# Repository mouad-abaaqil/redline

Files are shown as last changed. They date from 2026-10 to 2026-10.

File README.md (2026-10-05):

<p align="center">
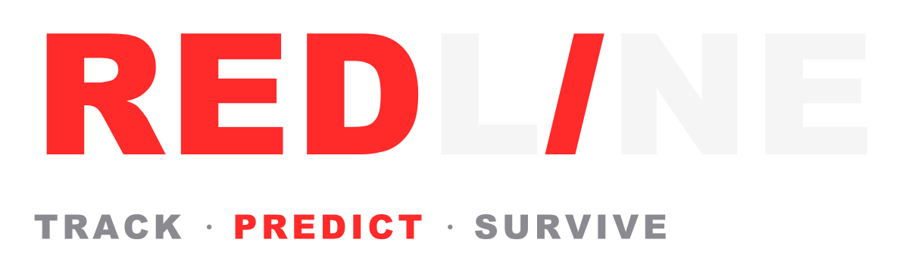
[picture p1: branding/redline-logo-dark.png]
Redline: Track, Predict, Survive
  
</p>

<h1 align="center">Know where it is.<br>Know when it lands.<br><span>Know what happened.</span></h1>

<p align="center">
  <strong>Redline</strong> is a free, open source tracker and black box for freight.<br>
  It knows its exact position, predicts its arrival from real open traffic data, spots a detour or a theft, and keeps talking when every normal network is gone.
</p>

<p align="center">
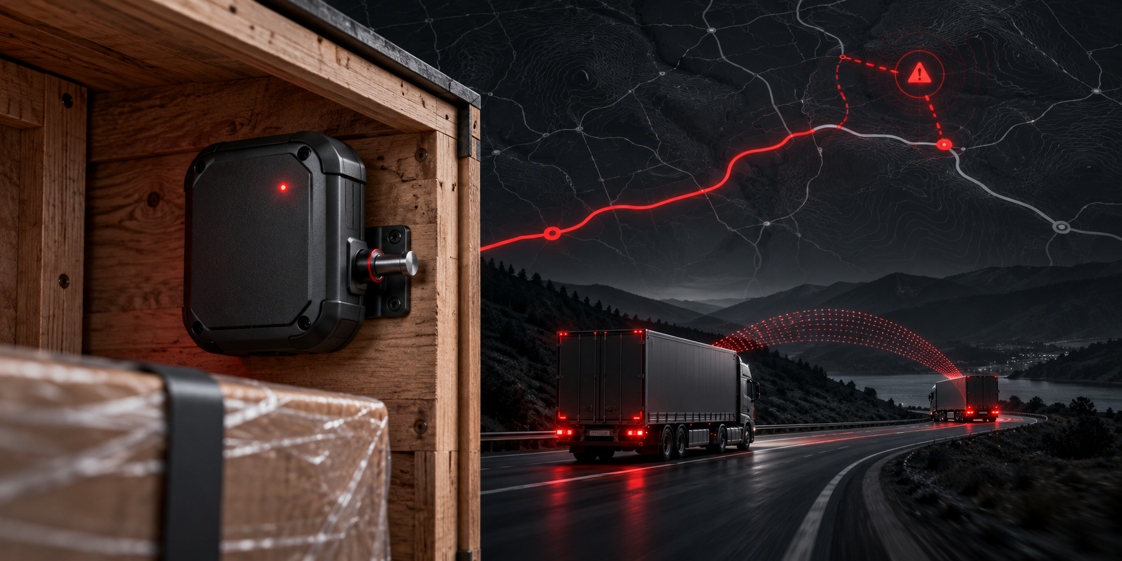
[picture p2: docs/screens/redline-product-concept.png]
Concept illustration of the Redline freight tracker monitoring cargo, route deviation, and a fleet relay
  
</p>
<p align="center"><sub>Product concept: a tracker watching cargo on the road, with route deviation and fleet relay shown around it. This is an illustration, not a photograph of a manufactured device.</sub></p>

<p align="center">
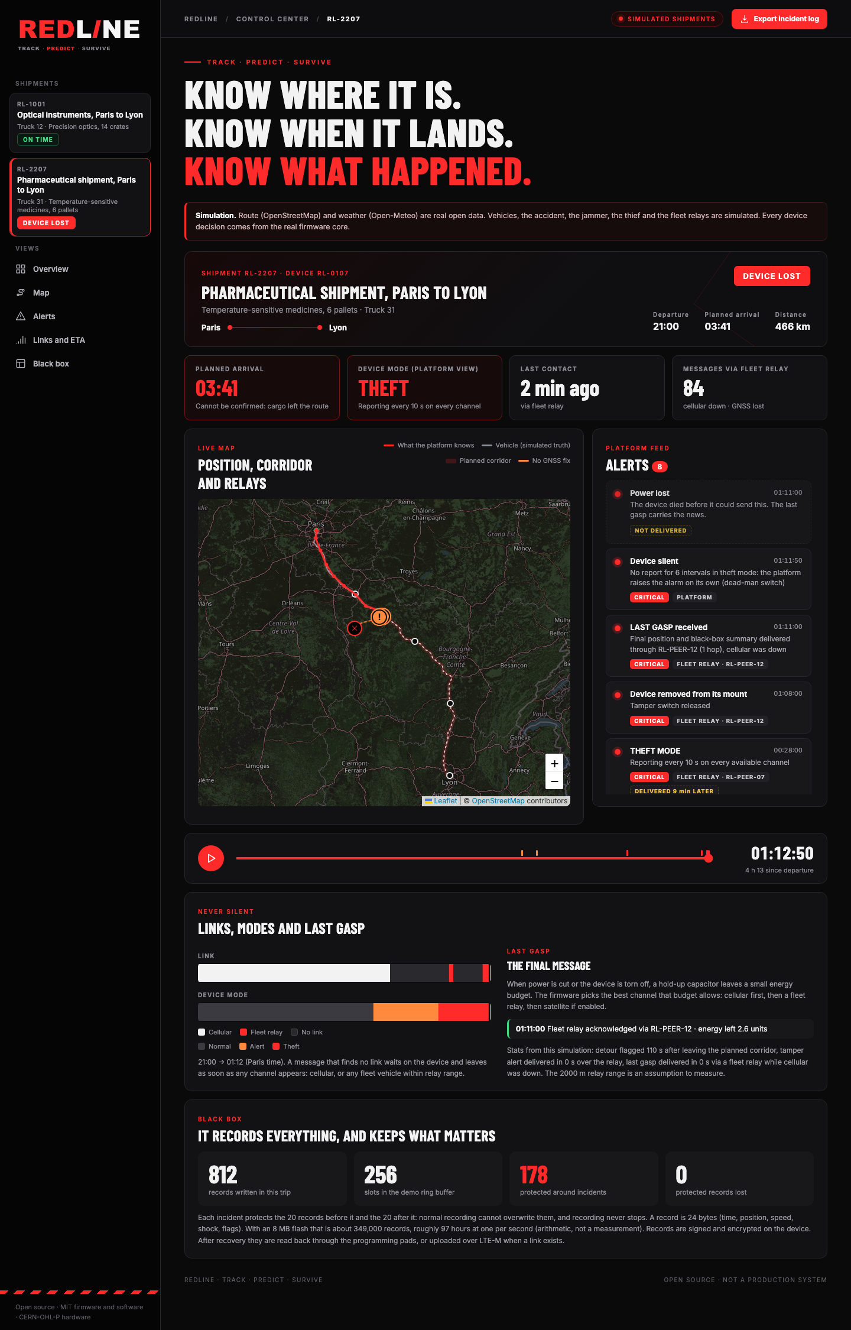
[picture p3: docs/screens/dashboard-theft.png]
Redline control center showing a suspected theft: the platform feed, the map with the planned corridor and the last gasp
  
</p>
<p align="center"><sub>The control center replaying a simulated theft. The road and weather use open data; vehicles, theft events, and fleet relays are simulated. Device decisions come from the firmware core.</sub></p>

> **Successor of [TiltAlert](https://github.com/mouad-abaaqil/TiltAlert).** TiltAlert counts the shocks a parcel takes. Redline tells you where the whole shipment is, when it will arrive, whether it is still on its route, and what happened to it, even if nobody ever finds the device.

---

## 1. The problem: freight goes dark

A truck leaves Paris with six pallets of medicines. Somewhere near Auxerre it takes a road that is not on the plan. Twenty minutes later the cellular network drops. An hour after that the cargo is gone.

What the operator has at that point:

- **A promise, not a prediction.** The ETA was computed at departure. It knows nothing about the accident ahead or the fog that is already there.
- **A tracker that stops talking exactly when it matters.** Thieves jam GNSS and cellular, or just drive into a valley with no coverage.
- **No black box.** When the device is torn off and thrown away, everything it knew goes with it.
- **Tools you rent, with data you do not own.** The price is per device per month and the logic is a secret.

## 2. The solution: three promises, one device

### TRACK: exact position, and the discipline to notice when something is wrong

- **Position** from GNSS, reported every 15 minutes in normal mode, every 60 s in alert mode, every 10 s in theft mode.
- **Route corridor.** The planned route is loaded in the device with a corridor around it. Leaving it for 2 minutes raises an alert. This runs **on the device**, so it works with no network and the alert leaves as soon as any link appears.
- **Unauthorized stop.** Ten minutes still outside every authorized zone (depots, planned rest stops) is flagged. If GNSS is jammed, the accelerometer still says whether the vehicle moves.
- **Theft rules.** Movement while parked and armed, the device pulled off its mount (a spring plunger and a switch), the cover opened, the power cut, and GNSS lost *while the cellular link is healthy*, which points to a jammer. Each condition has a weight: a detour alone raises an alert, a tamper alone is theft.
- **Shock.** The shock sensor of TiltAlert (±200 g) stays, now feeding the black box.

### PREDICT: an arrival time that listens to the road

The engine ([`web/src/eta.js`](./web/src/eta.js), 8 unit tests) is pure and replayable. It combines:

| Input | Source | Cost |
| --- | --- | --- |
| Road network and free-flow speeds | [OpenStreetMap](https://www.openstreetmap.org/copyright), routed by [OSRM](https://project-osrm.org/) (Valhalla also supports per-hour speed profiles) | free |
| Traffic situations (accidents, roadworks) | National access points publishing [DATEX II](https://www.datex2.eu/), for example [transport.data.gouv.fr](https://transport.data.gouv.fr/) | free |
| Weather: rain, visibility, wind | [Open-Meteo](https://open-meteo.com/en/about) (CC BY 4.0, free for open source, self-hostable) | free |
| What the fleet actually measures | Speeds from the trackers themselves | free |
| Mandatory driver breaks | 45 min after 4.5 h of driving (rule to check per vehicle class) | free |

A traffic situation only counts **once it has been published**: the estimate never uses information that did not exist yet.

### SURVIVE: the device that never goes silent

- **Black box.** Every second: position, speed, shock, link state, tamper. In a ring buffer where the 20 records before and after each incident are **protected** from being overwritten. Recording never stops. Records are signed and encrypted.
- **Three communication layers.** Cellular LTE-M/NB-IoT first. When it is down, a **fleet relay**: the message hops through any Redline device in range, over DECT NR+ mesh, like Find My but for freight. Satellite NB-NTN is an option, off by default (it is the only paid layer).
- **Last gasp.** A hold-up supercapacitor leaves a small energy budget when the device is torn off or the supply is cut. The firmware spends it on the best channel available: cellular, then a fleet relay, then satellite.
- **Dead-man switch.** If the device stops reporting while in theft mode, the platform raises the alarm itself.

---

## 3. See it work

Two simulated shipments, Paris to Lyon (465 km, the real road, the real forecast). Open [`web/`](./web/) and replay them.

### Shipment 1: the arrival time that learns

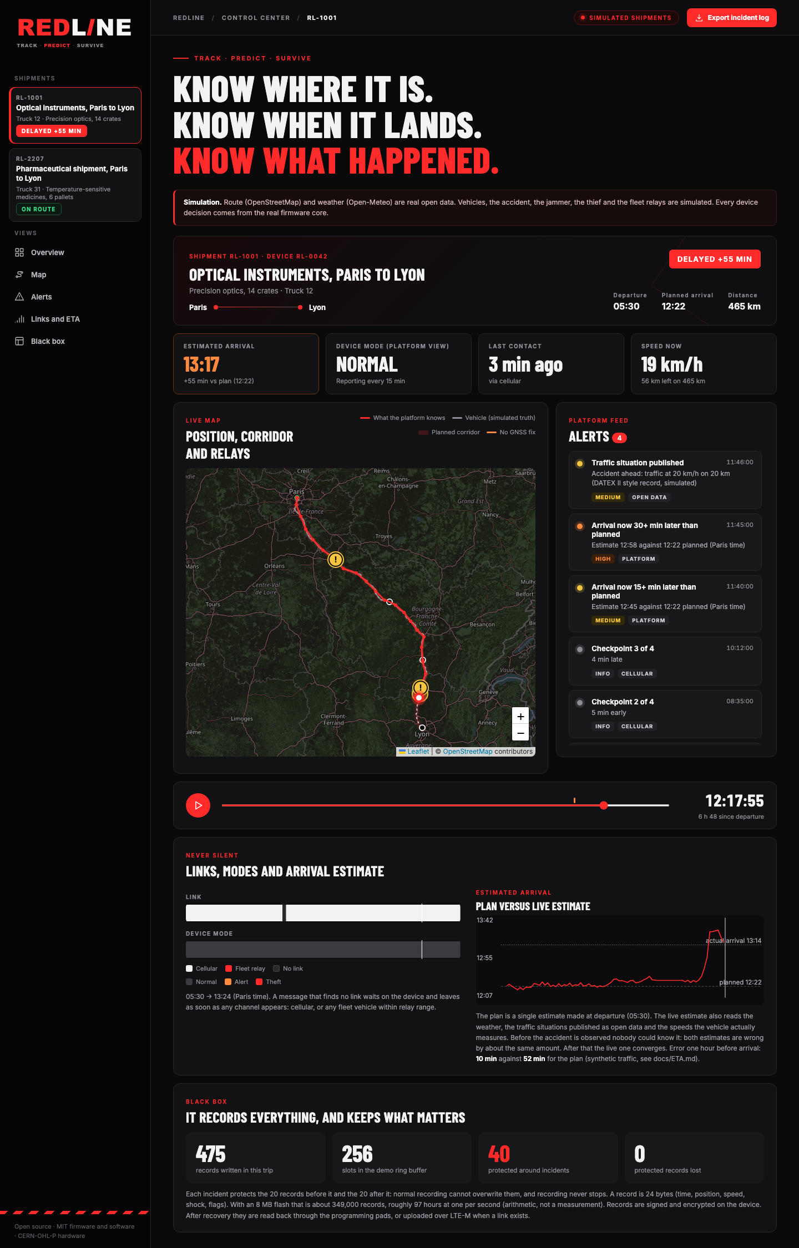
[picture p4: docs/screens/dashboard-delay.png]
The delayed shipment: arrival estimate, accident, link and mode strips


A truck leaves at 05:30 (Paris time) and the plan says it will arrive at 12:22. On the road it meets **real fog** (visibility down to 20 m on the forecast) and a **simulated accident** published at 11:46. It arrives at 13:14, **52 minutes late**.

| | Error on the arrival time |
| --- | --- |
| The plan made at departure | 52 min |
| Live estimate, 60 min before arrival | **10 min** |
| Live estimate, 15 min before arrival | **1 min** |

The live estimate cannot know about an accident before it is published: for the first hours it is as wrong as the plan. Once the situation is published and the truck slows down, it converges. The traffic pattern is synthetic, so these numbers show the mechanism, not a field result ([details](./docs/ETA.md)).

### Shipment 2: theft, jamming, and a last word through a stranger

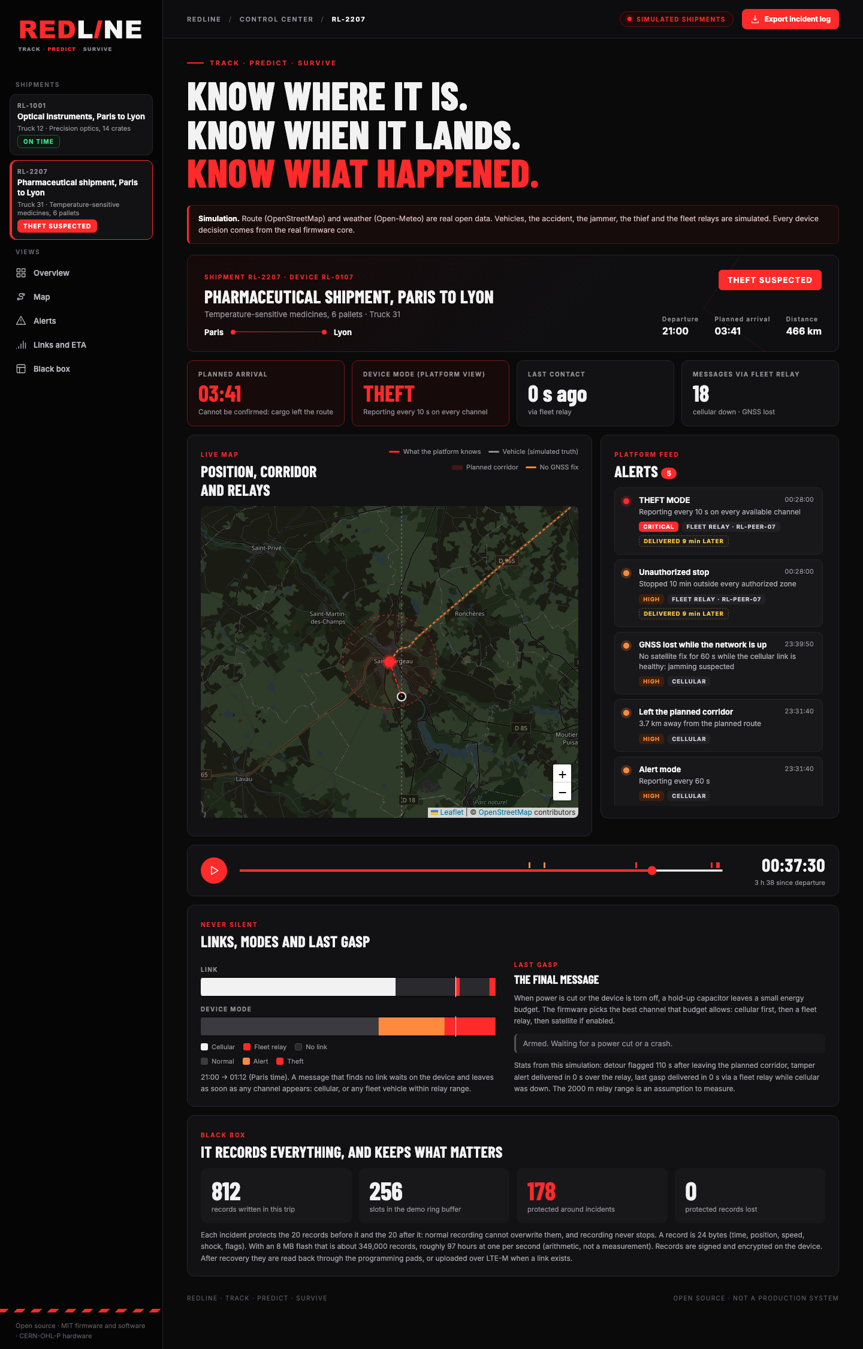
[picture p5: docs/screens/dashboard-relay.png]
The theft shipment 38 minutes later, relay message delivered


1. **21:31** The truck leaves the corridor. Alert delivered over cellular in about 2 minutes.
2. **21:39** GNSS lost while cellular is up: jamming suspected.
3. **22:28** The truck stops 10 minutes at an isolated site. Cellular is gone, so the **theft alert waits on the device for 9 minutes**, then goes through a passing fleet truck (RL-PEER-07).
4. **23:08** The device is torn off its mount. Tamper alert delivered **instantly** through another fleet truck.
5. **23:11** Power cut. The **last gasp** leaves in the same second over the fleet relay. The platform also raises a *device silent* alarm on its own.
6. Black box: 812 records, **178 protected** around the incidents, **0 lost**.

The 2 km relay range and the energy costs are **assumptions to measure on hardware**.

### The hardware, all components on one page

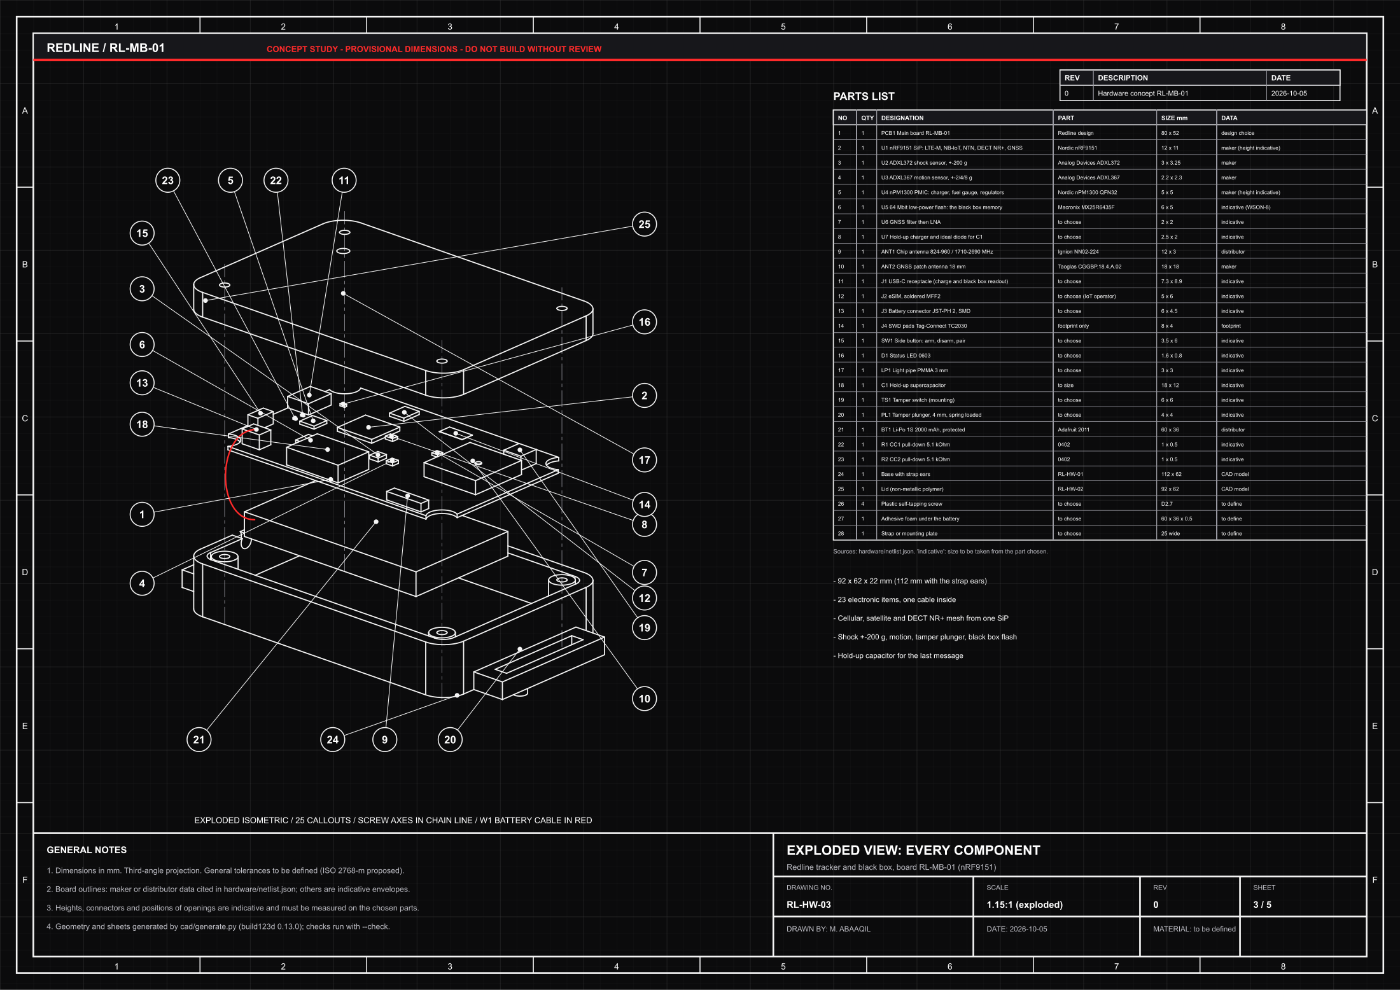
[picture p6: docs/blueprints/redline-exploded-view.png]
Exploded view of the Redline tracker: 25 callouts, parts list, battery cable


Five A3 sheets in a blackprint style, all generated from the 3D model and the netlist ([PDF, 5 pages](./docs/blueprints/redline-plans-A3.pdf)): general assembly with section, the board with the **tamper mechanism** in detail, the exploded view above, the electrical architecture, and the full wiring (33 nets, connector pin-outs, the one cable, power-up sequence).

<details>
<summary><strong>The other four sheets and the interface blueprint</strong></summary>

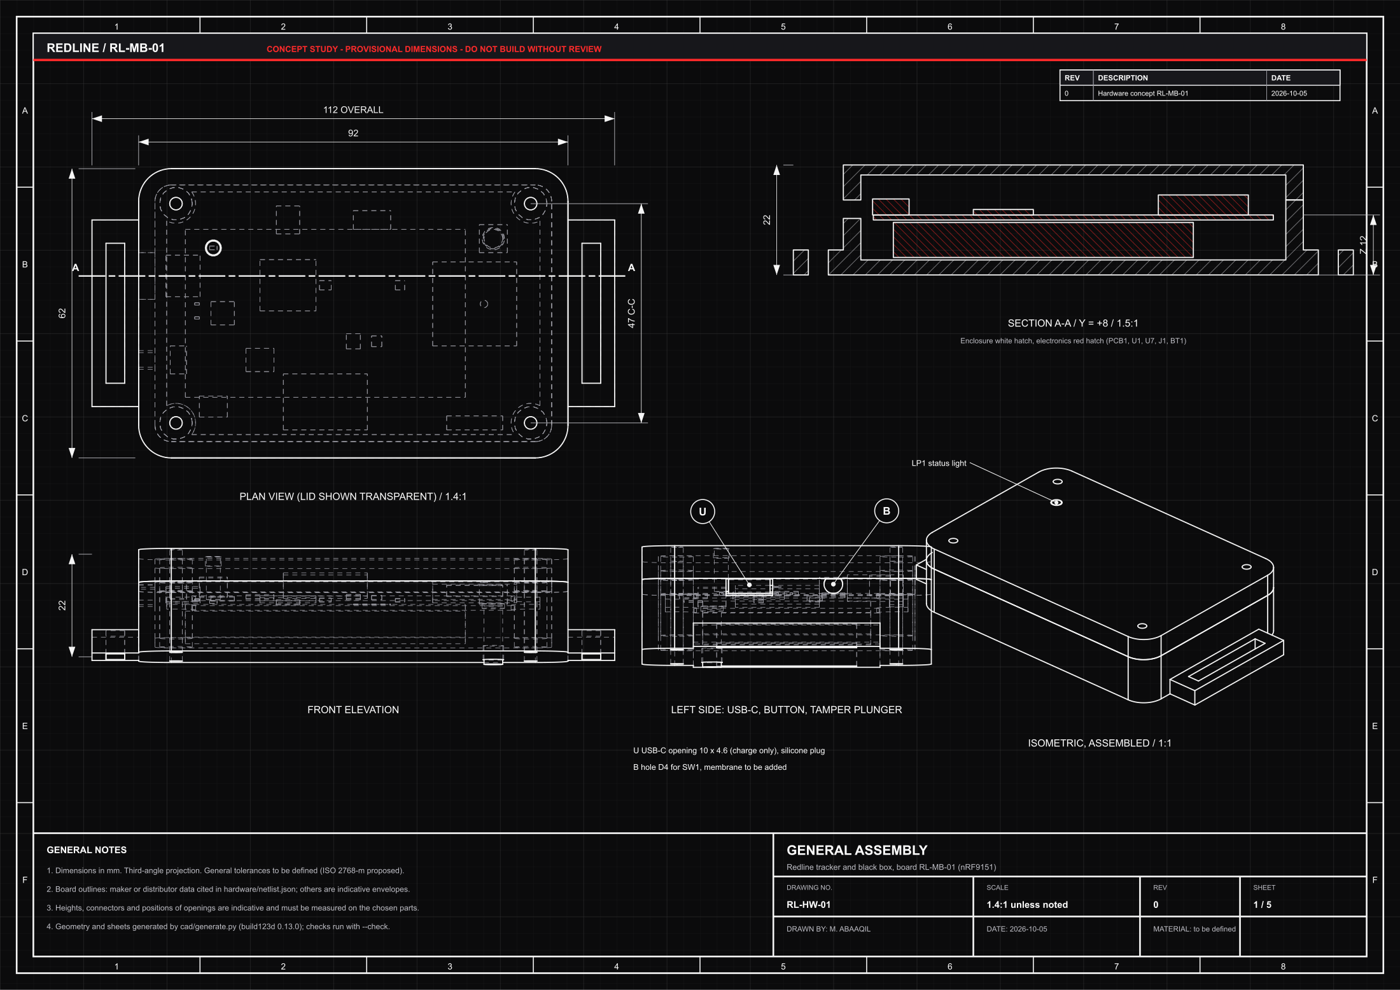
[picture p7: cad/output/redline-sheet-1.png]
Sheet 1: general assembly


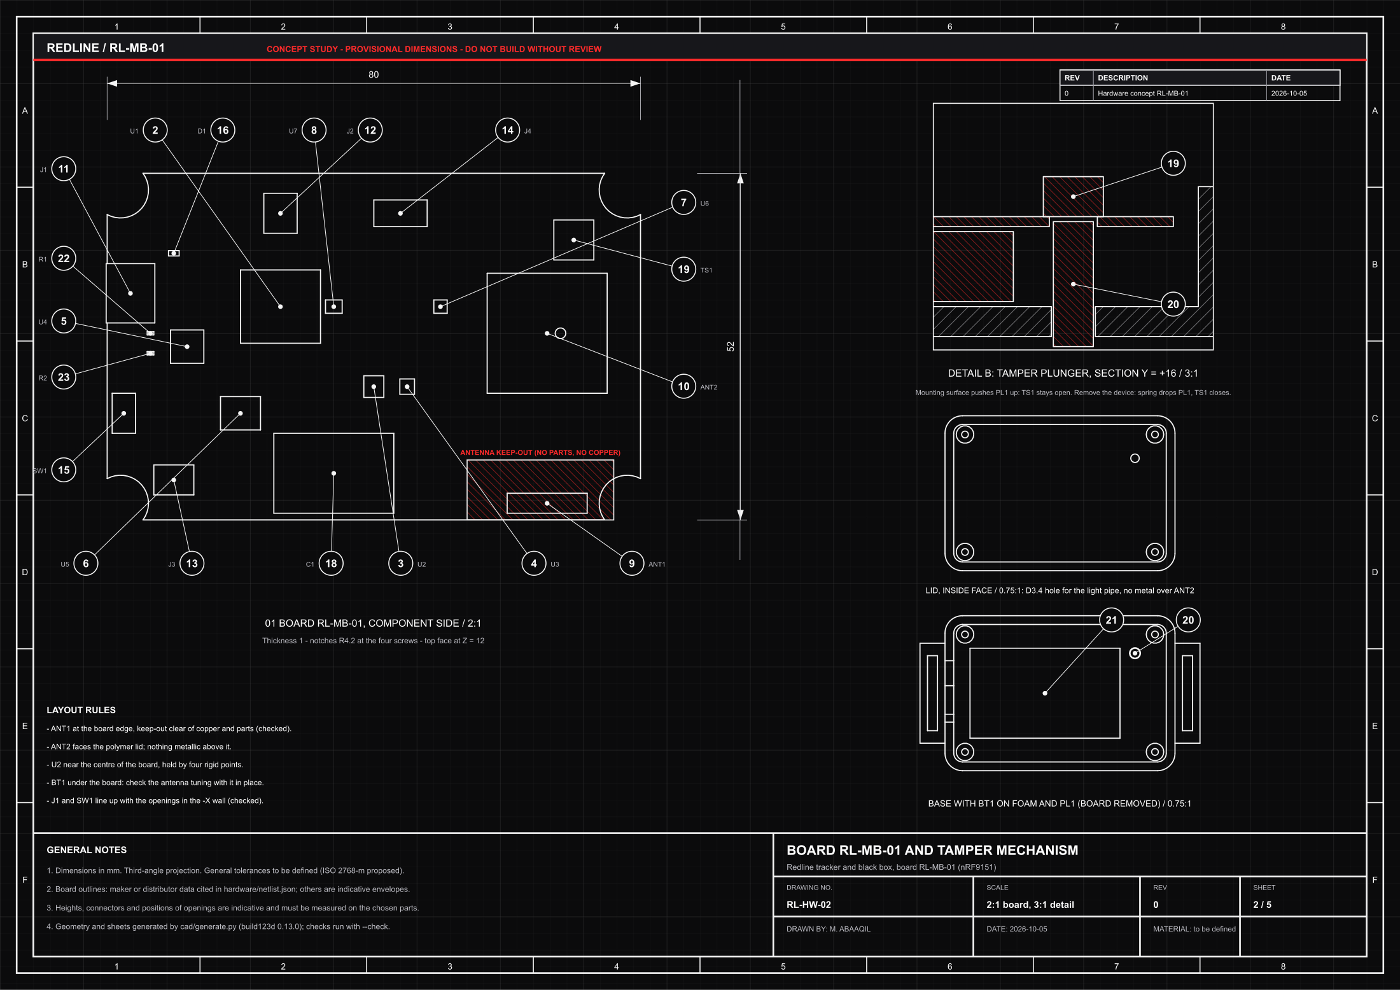
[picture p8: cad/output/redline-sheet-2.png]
Sheet 2: board RL-MB-01 and tamper mechanism


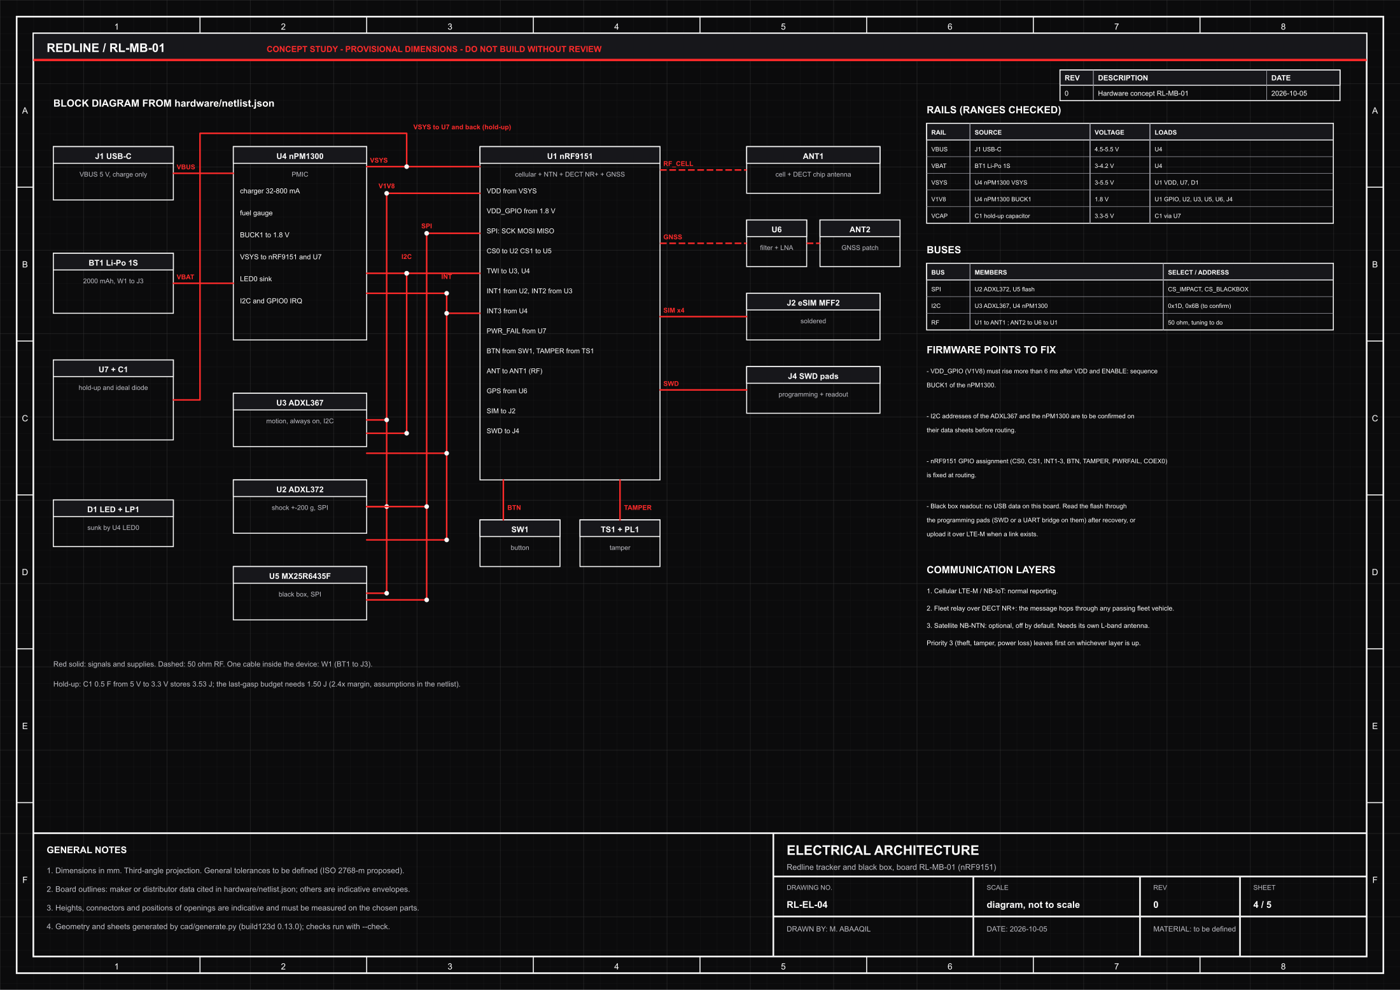
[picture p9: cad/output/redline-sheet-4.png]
Sheet 4: electrical architecture


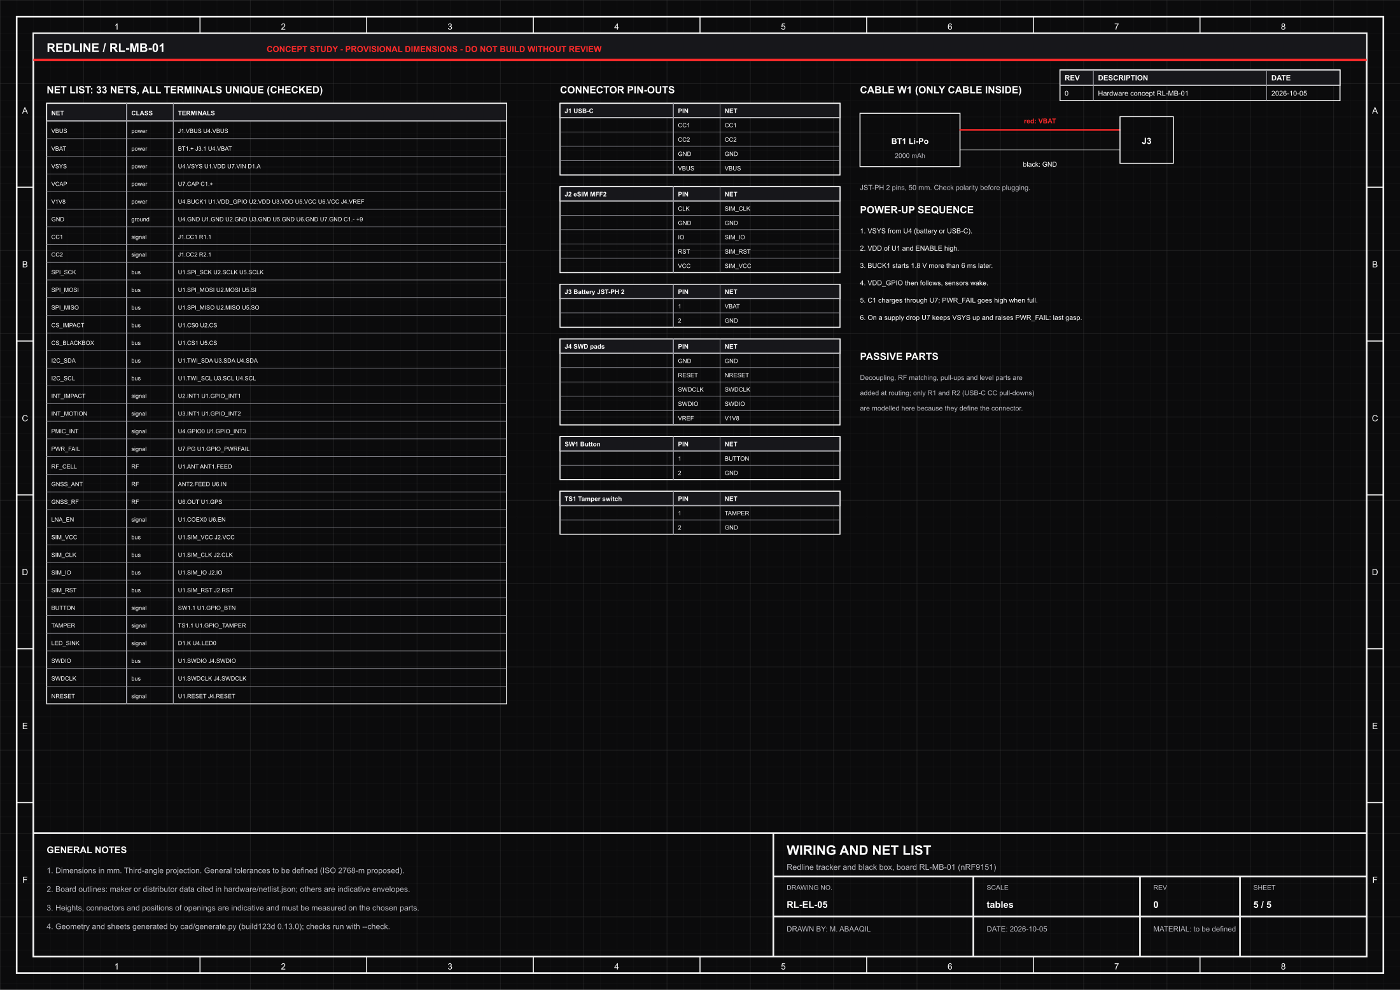
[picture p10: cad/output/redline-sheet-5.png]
Sheet 5: wiring and net list


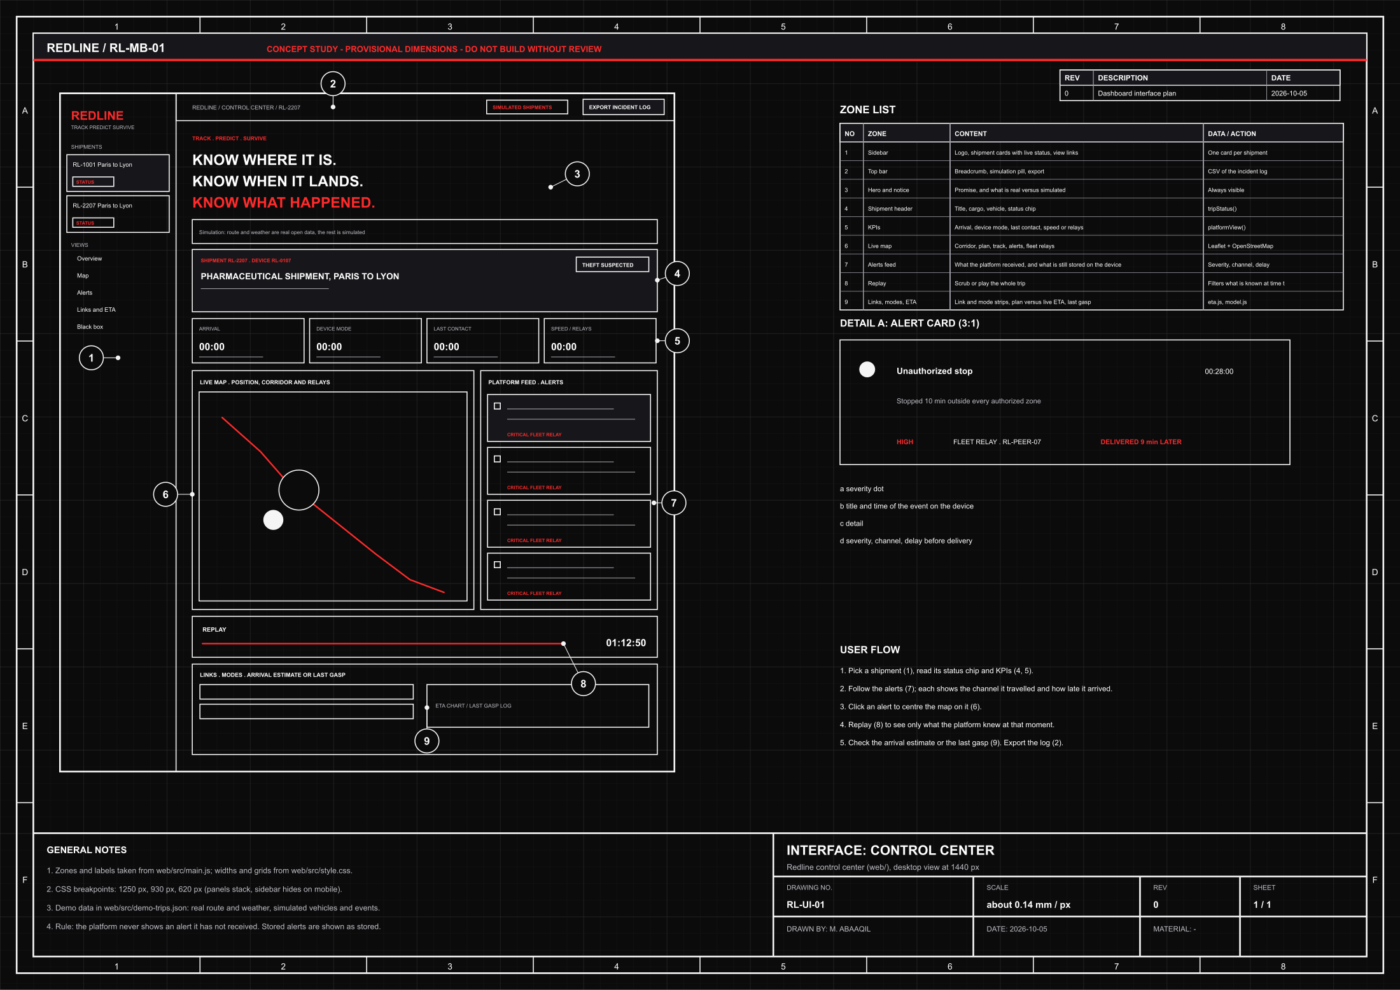
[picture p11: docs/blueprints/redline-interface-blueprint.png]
Interface blueprint of the control center


</details>

---

## 4. Under the hood

One custom board, **RL-MB-01**, in a 92 × 62 × 22 mm enclosure. Every part is in [`hardware/netlist.json`](./hardware/netlist.json) with its source.

| Function | Part | Why |
| --- | --- | --- |
| Brain, cellular, mesh, satellite, GNSS | [Nordic nRF9151](https://www.nordicsemi.com/products/nrf9151) | One SiP supports LTE-M, NB-IoT, [NB-NTN satellite](https://www.nordicsemi.com/products/nrf9151), DECT NR+ mesh and GNSS. |
| Shock, black box trigger | [ADXL372](https://www.analog.com/en/products/adxl372.html), ±200 g | Peak capture and FIFO for the pre-trigger waveform. |
| Motion, always on | [ADXL367](https://www.analog.com/en/products/adxl367.html) | Wakes the system, tells moving from still when GNSS is jammed. |
| Power | [nPM1300](https://www.nordicsemi.com/Products/nPM1300) | Charger, fuel gauge, regulators in one chip. |
| Black box memory | 64 Mbit low-power flash | About 349,000 records of 24 bytes, roughly 97 hours at 1 Hz (arithmetic, not a measurement). |
| Last gasp | Supercapacitor 0.5 F + hold-up charger | 3.5 J stored against 1.5 J needed (2.4×, assumptions in the netlist). |
| Tamper | Spring plunger + switch | The mounting surface holds the switch open; removal closes it. |
| Antennas | Chip antenna (cellular, DECT) + GNSS patch | Keep-out zone enforced in the model. The satellite layer needs its own L-band antenna. |

### A design that checks itself

Every time the drawings are generated, a script verifies that:

- all **23 parts fit** the enclosure without touching a wall, a screw boss or each other (≥ 0.2 mm);
- every **supply rail is inside the range** of every part it powers, and no rail is shorted to another;
- **SPI chip selects and I²C addresses** are distinct;
- the **antenna keep-out** is empty, and no part hangs over a screw notch of the board;
- the **USB-C and button openings** really cross the wall in front of their parts;
- the **hold-up capacitor stores at least twice** the energy the last-gasp budget needs.

### The firmware core is tested, not just written

[`firmware/RedlineCore.h`](./firmware/RedlineCore.h) is plain C++11 with no heap and no dependency, so the same code runs in the tests, in the simulation and on the device. `sh tests/run.sh` runs 9 test groups: geometry, route deviation with hysteresis, stops, schedule, jamming, theft rules, the black box ring buffer, the last-gasp channel choice, and the relay queue with priorities and duplicate protection.

```mermaid
flowchart LR
  A[ADXL372 shock] --> M[nRF9151 + Redline core]
  B[ADXL367 motion] --> M
  T[Tamper plunger] --> M
  G[GNSS] --> M
  M --> K[(Black box flash)]
  M -->|1 normal| C[Cellular LTE-M / NB-IoT]
  M -->|2 no network| R[Fleet relay: DECT NR+ mesh]
  M -->|3 optional| S[Satellite NB-NTN]
  C & R & S --> P[Platform: ETA, alerts, dead-man switch]
  O[(Open data: OSM, DATEX II, Open-Meteo)] --> P
  H[Hold-up capacitor] -.last gasp.-> M
```

---

## 5. Honest status

| ✅ Proven in this repository | 🔬 To prove on real hardware |
| --- | --- |
| Core logic: deviation, stops, schedule, jamming, theft score, black box, last gasp, relay queue (tested C++). | Detection thresholds and false positives on real trucks. |
| ETA engine: breaks, rush hour, weather, published incidents, fleet correction (tested JS). | Accuracy on real traffic, against a measured weekly speed profile. |
| Two end-to-end simulated trips with real route and weather data, replayed in the dashboard. | Mesh range, relay behaviour in a moving fleet, DECT NR+ with real firmware. |
| Hardware checked by script: fit, rails, buses, keep-out, hold-up energy. | Antenna tuning with the battery in place, satellite layer, hold-up ESR during the LTE-M burst. |
| Plans, STEP and STL generated from the model. | Autonomy, enclosure test, transport of lithium cells (regulated). |

**Not claimed:** any accuracy, autonomy or cost figure. GNSS jamming detection is an aid, not a guarantee. A signature proves a log was not altered, not that a court accepts it. Satellite service in Europe depends on operators such as [Skylo](https://www.skylo.tech/newsroom/deutsche-telekom-murata-and-skylo-technologies-announce-satellites-nb-iot-ntn-early-adopter-program-for-europe) and costs money.

**Privacy.** Redline tracks **cargo, not people**. Using location data on a driver falls under labour law and the GDPR in Europe. See [`docs/PRIVACY_AND_ETHICS.md`](./docs/PRIVACY_AND_ETHICS.md): design rules, and what the system deliberately does not do.

### Next

1. Write the firmware on a [Nordic Thingy:91 X](https://docs.nordicsemi.com/r/bundle/ug_thingy91x/page/ug/thingy91x/intro/frontpage.html) (same SiP and PMIC): core logic, black box, LTE-M reporting.
2. Measure a weekly speed profile on a real corridor and replace the synthetic traffic pattern.
3. Test fleet relay range with two or three devices.
4. Route the PCB (4 layers), RF review, hold-up measurements.
5. Prototype the enclosure and test the tamper mechanism.

---

## 6. Explore the repository

| | |
| --- | --- |
| [`web/`](./web/) | Control center: live map, alerts with channel and delay, replay, ETA chart, last gasp, black box, CSV export. |
| [`firmware/RedlineCore.h`](./firmware/RedlineCore.h) | The device logic, tested. |
| [`simulation/`](./simulation/README.md) | Trip runner (links the real core), real route and weather snapshots, scenario generator. |
| [`hardware/`](./hardware/README.md) | Netlist, component choices, checks, points to settle before routing. |
| [`cad/`](./cad/README.md) | Parametric enclosure and the five A3 sheets (build123d). |
| [`docs/`](./docs/) | [Architecture](./docs/ARCHITECTURE.md) · [ETA](./docs/ETA.md) · [Mesh and last gasp](./docs/MESH_AND_LAST_GASP.md) · [Privacy and ethics](./docs/PRIVACY_AND_ETHICS.md) |
| [`branding/`](./branding/) | The logo files (SVG, generated). |

## 7. Run it

```bash
sh scripts/check.sh                 # all tests and checks (see below)

# Control center
cd web && npm ci && npm run dev     # then open the address Vite prints

# Regenerate the hardware drawings (Python 3.12, rsvg-convert)
python3.12 -m venv .venv && .venv/bin/pip install -r cad/requirements.txt
.venv/bin/python cad/generate.py            # sheets, STEP, STL
python3 docs/interface/generate.py          # interface blueprint

# Regenerate the simulated trips (only needs g++ and Node 20+)
node simulation/fetch-data.mjs              # optional: refresh the open-data snapshots
node simulation/make-scenario.mjs           # rebuilds web/src/demo-trips.json
```

`scripts/check.sh` runs the C++ tests, the web tests (ETA engine and dashboard model), the geometry and netlist checks, and rebuilds the dashboard.

## 8. Open source, for real

| | License |
| --- | --- |
| Firmware, software, simulation, drawings code | [MIT](./LICENSE) |
| Hardware design (netlist, enclosure model, plans) | [CERN-OHL-P v2](./LICENSE-HARDWARE.txt) (permissive) |
| Data | OpenStreetMap contributors (ODbL), Open-Meteo (CC BY 4.0). See [NOTICE](./NOTICE.md). |

---

<p align="center">
  <strong>REDLINE</strong> · Track · Predict · Survive<br>
  <sub>A concept with checked foundations, not a product. Dimensions and architecture are not validated for manufacture.</sub>
</p>

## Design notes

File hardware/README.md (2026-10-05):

# Hardware: board RL-MB-01

**Status: design with sourced parts. The PCB is not routed, nothing is built or measured.**

[`netlist.json`](./netlist.json) is the single source: 23 components with a size, a source or an "indicative" mark, 33 nets, rails with their ranges, buses, the one cable, and the hold-up assumptions. The drawings in [`../cad/`](../cad/README.md) are generated from it.

## What changed from TiltAlert

TiltAlert V1 is an Arduino Uno with a tilt contact. Its V2 study used a tracker with GNSS and LTE-M. Redline keeps that core (nRF9151, ADXL372, ADXL367, nPM1300, black box flash) and adds what the new product needs: a **hold-up capacitor** (U7, C1) for the last gasp, a **tamper mechanism** (TS1 with a spring plunger PL1 through the floor), the **DECT NR+ and NTN** layers (same SiP, no new chip), and an enclosure sized for it.

## Parts and sources

| Ref | Part | Source |
| --- | --- | --- |
| U1 | Nordic nRF9151 | https://www.nordicsemi.com/products/nrf9151 |
| U2 | Analog Devices ADXL372 | https://www.analog.com/en/products/adxl372.html |
| U3 | Analog Devices ADXL367 | https://www.analog.com/en/products/adxl367.html |
| U4 | Nordic nPM1300 | https://www.nordicsemi.com/Products/nPM1300 |
| U5 | Macronix MX25R6435F | https://www.mouser.fr/new/macronix/macronix-mx25r-nor-flash |
| ANT1 | Ignion NN02-224 | https://www.digikey.ph/en/products/detail/ignion/NN02-224/10108260 |
| ANT2 | Taoglas CGGBP.18.4.A.02 | https://www.taoglas.com/product/cggbp-18-4-a-02-gpsglonassbeidou-patch-antenna-18mm-2 |
| BT1 | Adafruit 2011 (3.7 V, 2000 mAh) | https://www.adafruit.com/product/2011 |

Parts marked "to choose" (USB-C, eSIM, connectors, button, LED, light pipe, hold-up charger, capacitor, tamper switch and plunger) have indicative envelopes only.

## Points to settle before routing

1. **Satellite antenna.** The chip antenna covers 824-960 and 1710-2690 MHz. NB-NTN uses L-band near 1.6 GHz, which is not covered. If the satellite layer is enabled it needs its own antenna and a coexistence plan with the GNSS patch.
2. **Hold-up.** The 0.5 F value and the energy unit are assumptions. Measure the capacitor ESR against the LTE-M burst current, and the real energy of a last-gasp message on each channel.
3. **Sequencing.** VDD_GPIO (1.8 V) must rise more than 6 ms after VDD and ENABLE: program BUCK1 of the nPM1300 accordingly.
4. **I²C addresses** of the ADXL367 (0x1D planned) and nPM1300 (0x6B planned) to confirm on the data sheets.
5. **GPIO assignment** of the nRF9151 (CS0, CS1, INT1-3, BTN, TAMPER, PWRFAIL, COEX0) to fix at routing.
6. **Black box readout.** The nRF9151 has no native USB, so the board has no USB data. Read the flash through the programming pads after recovery, or upload it over LTE-M. A USB bridge could be added.
7. **Tamper.** The plunger and spring, their travel and the mounting plate need a mechanical design and a test. A thief can defeat a switch with the right tool: treat it as one signal among several.
8. **Antenna tuning** with the battery in place and the lid on; the lid must stay non-metallic.
9. **Lithium cells** in air transport are regulated: check the rules for the chosen cell and quantity.
10. **Supply margin.** VSYS on battery falls to 3.0 V at cutoff, exactly the minimum of the nRF9151 VDD. There is no margin for sag during a transmit burst: measure it, and stop earlier with a software threshold if needed.

## Validation order

1. Firmware on a Nordic Thingy:91 X: core logic, black box, LTE-M reporting.
2. Route the PCB on four layers, then an RF review.
3. Bring up: rails, sequencing, SWD, sensor reads, flash.
4. Calibrated shocks, tilts and false-positive tests with the board fixed in the enclosure.
5. GNSS quality outdoors and in a vehicle, then recording with no network.
6. Hold-up and last-gasp test, fleet relay range test with two or three devices.
7. Autonomy, charge and temperature tests before any claim.

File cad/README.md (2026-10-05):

# Enclosure and drawings

A parametric enclosure for the Redline tracker and the five A3 sheets that describe it, generated from one 3D model.

```sh
python3.12 -m venv .venv
.venv/bin/pip install -r cad/requirements.txt
.venv/bin/python cad/generate.py --check     # checks only
.venv/bin/python cad/generate.py             # sheets, PDF, STEP, STL
```

`rsvg-convert` is needed to produce the PDF and PNG files.

| File | Role |
| --- | --- |
| `generate.py` | Dimensions, enclosure, checks, the five sheets |
| `components.py` | The 23 parts as solids, the floorplan, the netlist validator |
| `drafting.py` | Shared A3 frame: zone border A to F and 1 to 8, revision and title blocks |
| `output/` | `redline-sheet-1..5` (SVG, PDF, PNG), base, lid and assembly STEP, base and lid STL |

## Sheets

1. General assembly: plan, front and side views, exact section through the USB-C port, isometric.
2. Board RL-MB-01 at 2:1 with callouts and the antenna keep-out, the tamper plunger in an exact section at 3:1, lid and base.
3. Exploded view of every part on one page with 25 callouts and a 28-line parts list.
4. Electrical architecture: block diagram, rails, buses, firmware points, communication layers.
5. Wiring: all 33 nets, connector pin-outs, the battery cable, power-up sequence.

The script also writes `docs/blueprints/redline-plans-A3.pdf` (the five sheets) and `redline-exploded-view.svg/png`.

## What `--check` proves

- The enclosure outline, wall openings and the four screw bores are consistent.
- All 23 parts lie inside the cavity and keep at least 0.2 mm from walls, screw bosses and each other. Parts on the board touch it by design only.
- No part enters the LTE antenna keep-out or hangs over a screw notch of the board.
- The netlist is valid: unique terminals and references, every supply pin on its rail with the rail inside the part's range, distinct SPI chip selects and I²C addresses, no short between VSYS, V1V8 and the hold-up rail, and the hold-up capacitor stores at least twice the last-gasp energy.

It does not replace a print test, a mechanical review, or an RF review.

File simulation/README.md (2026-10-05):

# Simulation

Two simulated shipments, Paris to Lyon, built from **real open data** and driven by the **real firmware core**.

```
simulation/data/            snapshots of real data: route-a.json, route-b.json, weather.json
simulation/runner.cpp       compiles with firmware/RedlineCore.h and runs it over a trip
simulation/make-scenario.mjs  builds the vehicles, injects the events, writes web/src/demo-trips.json
simulation/fetch-data.mjs   refreshes the snapshots from OSRM and Open-Meteo
```

## Run

```sh
node simulation/make-scenario.mjs      # needs g++ and Node 20+; rewrites web/src/demo-trips.json
node simulation/fetch-data.mjs         # optional: refetch the open data (network)
```

The generator is deterministic (seeded noise): the same data gives the same trips.

## What is real, what is simulated

| Real | Simulated |
| --- | --- |
| The road: 465 km Paris to Lyon with OpenStreetMap speeds, and a 52 km detour road | The vehicles and their speed noise |
| The weather forecast along the route, hour by hour (fog included) | The traffic accident (published at a chosen time) |
| Every device decision: the code of `RedlineCore.h` runs unchanged in `runner.cpp` | The GNSS jammer, the dead zone, the thief |
| The ETA engine `web/src/eta.js` | Fleet peers and their 2 km relay range (an assumption) |

The traffic congestion pattern in the ETA model is synthetic (see [../docs/ETA.md](../docs/ETA.md)).

## Trips

**RL-1001, the arrival time that learns.** A truck leaves at 05:30 (Paris time), planned arrival 12:22. It meets real fog and a simulated accident. It arrives at 13:14, 52 minutes late. The plan is off by 52 min; the live estimate is off by 10 min one hour before arrival and by 1 min fifteen minutes before. One shock is recorded and sent. The platform raises two ETA-slip alerts. Cellular coverage is lost in one valley and the stored reports go out afterwards.

**RL-2207, theft.** The truck leaves the corridor, GNSS is jammed, the truck stops at an isolated site and cellular is gone. The stop alert waits 9 minutes for a fleet relay. The device is torn off, then its power is cut: the tamper alert and the last gasp go over the fleet relay, and the platform raises the dead-man alarm.

## Runner protocol

`runner.cpp` reads lines: `CFG`, `G` (hold-up budget), `R` (route point), `Z` (authorized zone), `C` (checkpoint), `S` (one sample per tick). It writes JSON lines: `t` ticks, `e` device events, `d` delivered messages with their channel, `g` last-gasp attempts, and a final `end` summary of the black box.

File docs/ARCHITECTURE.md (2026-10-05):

# Architecture

Redline has three parts that only talk through messages: the **device**, the **links**, and the **platform**.

```
 device (RedlineCore + nRF9151)           links                       platform
 ┌──────────────────────────────┐   ┌────────────────────┐   ┌───────────────────────────┐
 │ sensors → Tracker (risk, mode)│   │ 1 cellular          │   │ receives messages         │
 │ BlackBox (ring, protected)    │──▶│ 2 fleet relay (mesh)│──▶│ ETA engine (eta.js)       │
 │ RelayQueue (store and forward)│   │ 3 satellite (opt.)  │   │ alerts, dead-man switch   │
 │ LastGasp (energy budget)      │   └────────────────────┘   │ control center (web/)     │
 └──────────────────────────────┘                             └───────────────────────────┘
```

## What runs where, and why

| Decision | Where | Reason |
| --- | --- | --- |
| Corridor, stop, jamming, theft score, mode | **Device** | Must work with no network. The alert is queued and leaves with the first link. |
| Which channel for which message | **Device** | Only the device knows which links are up and how much energy is left. |
| Arrival estimate | **Platform** | Needs open traffic and weather data and the speeds of the whole fleet. |
| *Device silent* alarm | **Platform** | A dead device cannot report its own death. |

## The device: `firmware/RedlineCore.h`

Plain C++11, no heap, no dependency. Fixed-size buffers: 400 route points, 16 zones, 16 checkpoints, a 256-slot black box in the demo.

- **`Tracker`**: takes one `Sample` per tick (position, speed, GNSS and cellular state, motion, tamper, power, shock, armed) and returns events. A condition must hold for a confirmation time before it fires (2 min for a deviation, 10 min for a stop, 60 s for GNSS loss, 10 s for movement while armed), and a deviation clears only inside 80 % of the corridor, to avoid flapping.
- **Risk and mode.** Each active condition adds a weight; the sum selects the mode. Deviation 40, stop 30, GNSS loss 40, armed motion 60, tamper 100, power loss 100. Alert starts at 40, theft at 100. **Theft is latched** until an operator acknowledges it. The mode sets the reporting interval: 15 min, 60 s, 10 s.
- **`BlackBox<N>`**: ring buffer. `flagIncident(pre, post)` protects the `pre` newest records and the next `post`. When every slot is protected, the oldest is overwritten so recording never stops (the count of overwritten protected records is kept).
- **`LastGasp`**: an energy budget. `next(links)` returns the best affordable channel: cellular, then mesh, then satellite, at most 2 tries per channel. Costs are relative units to calibrate on hardware.
- **`RelayQueue<N>`**: messages carry a priority (0 routine to 3 urgent), a TTL and a hop count. Duplicates are dropped, urgent messages leave first, a full queue evicts the oldest lowest-priority message, and a routine message never displaces an urgent backlog.

## The platform: `web/`

- `eta.js`: the estimate (see [ETA.md](./ETA.md)).
- `model.js`: `platformView(trip, t)` is the key function. It returns only what **was delivered** by time `t`. Everything else is shown as *stored on the device*. `tripStatus` turns that into the headline.
- `main.js`: rendering with Leaflet. The replay slider sets `t`; nothing the platform could not know at `t` is displayed.

## Data flow of one theft alert, in the simulation

1. `Tracker.update()` fires `unauthorized_stop` at 22:28:00 and the risk reaches theft level.
2. The runner creates a priority-3 message in the `RelayQueue`.
3. Cellular is down and no peer is in range: the message stays queued.
4. At 22:37:10 a fleet truck comes within 2 km. The message is popped and delivered through it.
5. `platformView` shows the alert from 22:37:10 with the badge *DELIVERED 9 min LATER*, and the event time stays 22:28:00.

## Simulation boundary

Simulated: vehicles, traffic accident, jammer, thief, fleet peers, radio. **Real:** the road geometry and speeds (OpenStreetMap), the weather (Open-Meteo), and every device decision (the core is compiled and run unchanged by `simulation/runner.cpp`). Radio range and energy costs are assumptions, listed in the README.

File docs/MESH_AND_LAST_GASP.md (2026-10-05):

# Fleet relay and last gasp

## The idea

Apple's Find My works because many devices carry a message that none of them can read. Redline applies the same principle to freight, with an operator-owned fleet instead of a consumer network: **any Redline device that is in range can carry another device's urgent message to the platform.**

## Layers

1. **Cellular (LTE-M / NB-IoT).** Normal reporting. Cheapest in energy per message.
2. **Fleet relay.** The [nRF9151](https://www.nordicsemi.com/products/nrf9151) supports DECT NR+, a mesh radio that needs no operator. A device with no link hands its message to a peer that has one. Messages carry a TTL (6 hops maximum), a priority, and an id so a message already seen is dropped.
3. **Satellite (NB-NTN).** Optional, off by default. The nRF9151 supports it, and services exist in Europe through operators such as [Skylo](https://www.skylo.tech/newsroom/deutsche-telekom-murata-and-skylo-technologies-announce-satellites-nb-iot-ntn-early-adopter-program-for-europe), but it costs money and needs its own L-band antenna (the chip antenna chosen does not cover it).

Priority 3 messages (theft, tamper, power loss) leave first, on whichever layer is up.

## Security model (design intent, not implemented)

- Messages are signed and encrypted end to end between the device and the platform. A relay sees an opaque payload and a priority byte, nothing more.
- A relay never reveals its own position in the message.
- Every device is provisioned with a key at manufacture. A stolen device can be revoked platform-side.

Not designed yet: key management, replay protection across devices, abuse by a malicious node flooding priority 3. These are real problems to solve before this could ship.

## Last gasp

When the supply drops (`PWR_FAIL`) or a crash is detected (shock ≥ 150 g), the firmware spends a fixed energy budget on the best affordable channel.

| Channel | Relative cost | Attempts |
| --- | --- | --- |
| Cellular | 1.0 | 2 |
| Fleet relay | 0.4 | 2 |
| Satellite | 2.5 | 2 |

The budget is 3.0 units. Hold-up check in `hardware/netlist.json`: a 0.5 F capacitor from 5 V to 3.3 V stores 3.53 J; if 1 unit is 0.5 J the budget needs 1.5 J, a 2.4× margin. **Both the unit and the 0.5 F are assumptions.** What decides it in practice is the capacitor's ESR during an LTE-M burst, which must be measured.

## What the simulation shows

In the theft shipment cellular is down for the last hour. The device keeps queuing. Passing fleet trucks (assumed 2 km range) carry 80 of its reports, the delayed theft alert, the tamper alert and the last gasp. The platform separately raises *device silent* when reports stop in theft mode.

## Limits

- A fleet relay only helps where other devices are. A truck alone on a mountain road has no relay.
- DECT NR+ range and behaviour in a moving fleet are unmeasured.
- Relaying consumes energy on devices that are not in trouble. The relay policy (when to accept, how many hops) needs a battery budget.

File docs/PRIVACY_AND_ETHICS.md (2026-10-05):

# Privacy and ethics

Redline tracks **cargo**. Position data attached to a vehicle is also, indirectly, data about the person driving it. In the European Union that falls under the GDPR and under employment law, and the rules differ by country. This file is a design stance, not legal advice.

## Rules the design follows

1. **The unit of tracking is the shipment.** The device is registered to a shipment, not to a driver. The demo data contains no driver identity.
2. **Track only while the cargo is on the move or armed.** Parked and disarmed at a depot, the device reduces its reporting. The route corridor and stops exist to protect the cargo, not to measure a person's behaviour.
3. **The driver is told.** A truck carrying a tracker is a workplace fact; drivers and their representatives must be informed. Rest-stop zones are authorized so that a legal break is never an alert.
4. **No performance scoring.** The break rule in the ETA engine exists to make the estimate honest about regulated rest. Nothing computes a driver's speed ranking, idle time, or stops for evaluation.
5. **Minimise and expire.** The black box and the platform keep what an incident needs. Retention periods must be set by the operator and the black box readout should be a controlled action.
6. **Open and auditable.** The detection logic is public so anyone can check what a device flags and why.

## What Redline deliberately does not do

- It does not identify or follow individuals, and has no map of where a person lives or goes outside the shipment.
- It does not hide itself from the person carrying the cargo by default (the status light can be disabled by the operator, which must be disclosed to the people concerned).
- It does not claim to detect theft with certainty. Jamming detection and the risk score are aids that can be wrong. An alert is a reason to look, not proof.

## Misuse

A tracker that survives removal and reports in secret is also a stalking tool when put on a person's belongings. The same properties that protect freight are dangerous in that use. The project is documented and licensed for freight. Hardware sold as a product would need anti-stalking measures such as alerting the people near an unknown moving tracker, and that is not designed here.

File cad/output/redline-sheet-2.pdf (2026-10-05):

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
A | A
B | B
C | C
D | D
E | E
F | F
REDLINE / RL-MB-01 | CONCEPT STUDY - PROVISIONAL DIMENSIONS - DO NOT BUILD WITHOUT REVIEW
REV | DESCRIPTION | DATE
0 | Hardware concept RL-MB-01 | 2026-10-05

### GENERAL NOTES

1. Dimensions in mm. Third-angle projection. General tolerances to be defined (ISO 2768-m proposed).
2. Board outlines: maker or distributor data cited in hardware/netlist.json; others are indicative envelopes.
3. Heights, connectors and positions of openings are indicative and must be measured on the chosen parts.
4. Geometry and sheets generated by cad/generate.py (build123d 0.13.0); checks run with --check.

## BOARD RL-MB-01 AND TAMPER MECHANISM

Redline tracker and black box, board RL-MB-01 (nRF9151)

DRAWING NO.

### RL-HW-02

SCALE

### 2:1 board, 3:1 detail

REV
0

SHEET
2 / 5
DRAWN BY: M. ABAAQIL | DATE: 2026-10-05 | MATERIAL: to be defined

ANTENNA KEEP-OUT (NO PARTS, NO COPPER)

U1 | 2
U4 | 5
U5 | 6 | 3 U2 | 4 U3

### 7 U6

U7 8

### 10 ANT2

### 9 ANT1

J1 | 11
SW1 | 15
D1 | 16 | J2 | 12
J3 | 13

## 14 J4

C1 18

### 19 TS1

R1 | 22
R2 | 23

80

52

### 01 BOARD RL-MB-01, COMPONENT SIDE / 2:1

Thickness 1 - notches R4.2 at the four screws - top face at Z = 12

### DETAIL B: TAMPER PLUNGER, SECTION Y = +16 / 3:1

Mounting surface pushes PL1 up: TS1 stays open. Remove the device: spring drops PL1, TS1 closes.

20

19

LID, INSIDE FACE / 0.75:1: D3.4 hole for the light pipe, no metal over ANT2

21 20

BASE WITH BT1 ON FOAM AND PL1 (BOARD REMOVED) / 0.75:1

LAYOUT RULES

- ANT1 at the board edge, keep-out clear of copper and parts (checked).
- ANT2 faces the polymer lid; nothing metallic above it.
- U2 near the centre of the board, held by four rigid points.
- BT1 under the board: check the antenna tuning with it in place.
- J1 and SW1 line up with the openings in the -X wall (checked).

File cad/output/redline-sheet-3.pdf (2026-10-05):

1

1

2

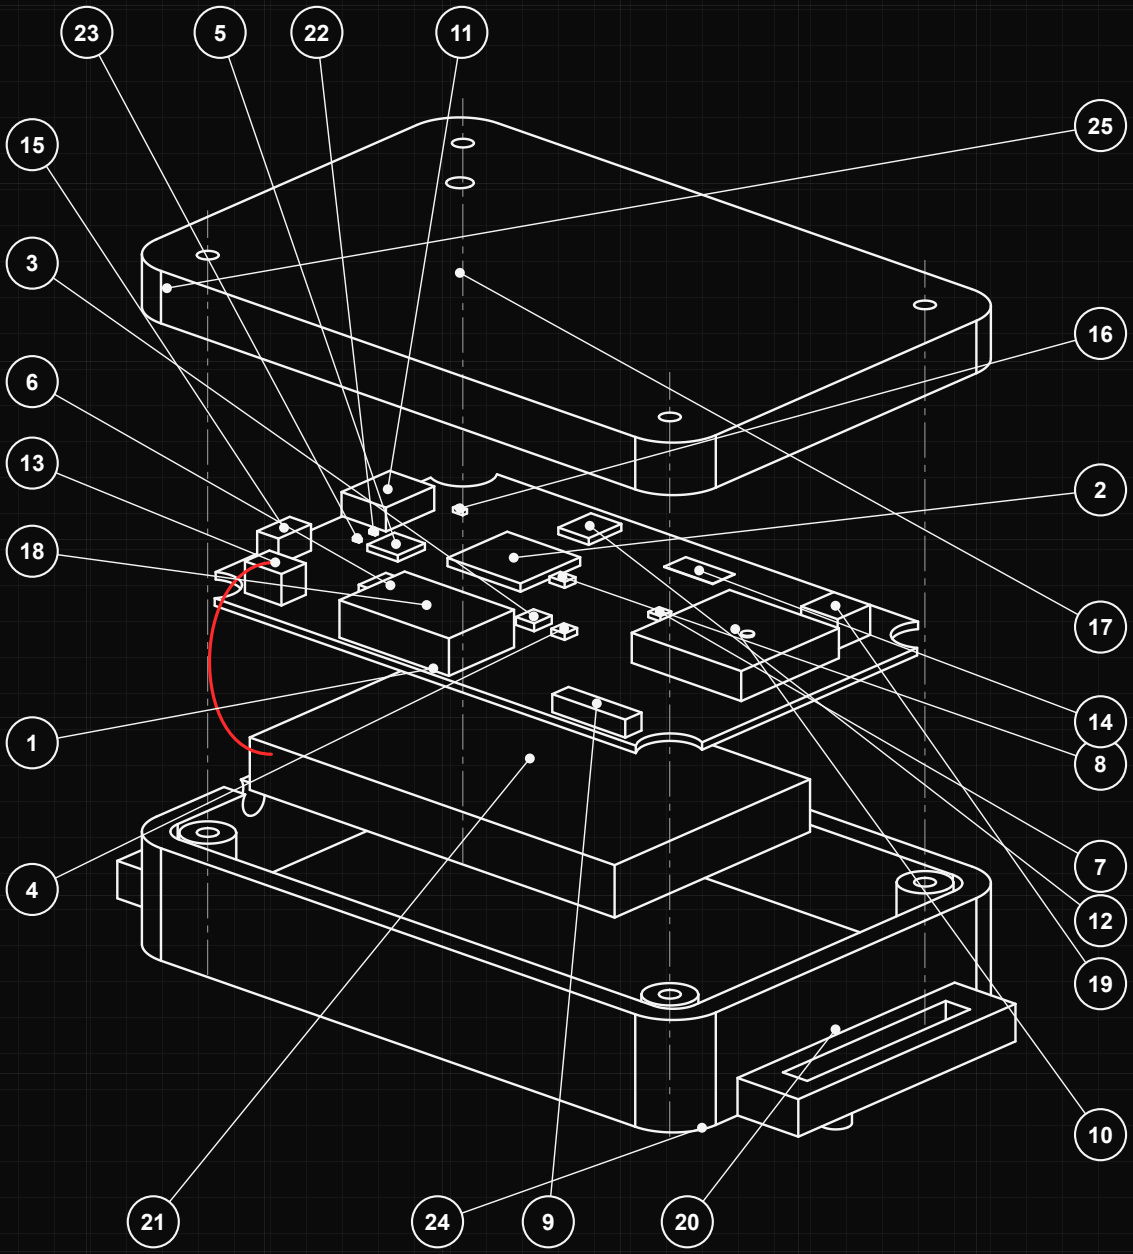
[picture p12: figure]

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
A | A
B | B
C | C
D | D
E | E
F | F
REDLINE / RL-MB-01 | CONCEPT STUDY - PROVISIONAL DIMENSIONS - DO NOT BUILD WITHOUT REVIEW
REV | DESCRIPTION | DATE
0 | Hardware concept RL-MB-01 | 2026-10-05

# GENERAL NOTES

1. Dimensions in mm. Third-angle projection. General tolerances to be defined (ISO 2768-m proposed).
2. Board outlines: maker or distributor data cited in hardware/netlist.json; others are indicative envelopes.
3. Heights, connectors and positions of openings are indicative and must be measured on the chosen parts.
4. Geometry and sheets generated by cad/generate.py (build123d 0.13.0); checks run with --check.

# EXPLODED VIEW: EVERY COMPONENT

## Redline tracker and black box, board RL-MB-01 (nRF9151)

DRAWING NO.

# RL-HW-03

## SCALE

# 1.15:1 (exploded)

## REV

0

## SHEET

3 / 5

DRAWN BY: M. ABAAQIL | DATE: 2026-10-05 | MATERIAL: to be defined

## EXPLODED ISOMETRIC / 25 CALLOUTS / SCREW AXES IN CHAIN LINE / W1 BATTERY CABLE IN RED

# PARTS LIST

NO | QTY | DESIGNATION | PART | SIZE mm | DATA
1 | 1 | PCB1 Main board RL-MB-01 | Redline design | 80 x 52 | design choice
2 | 1 | U1 nRF9151 SiP: LTE-M, NB-IoT, NTN, DECT NR+, GNSS | Nordic nRF9151 | 12 x 11 | maker (height indicative)
3 | 1 | U2 ADXL372 shock sensor, +-200 g | Analog Devices ADXL372 | 3 x 3.25 | maker
4 | 1 | U3 ADXL367 motion sensor, +-2/4/8 g | Analog Devices ADXL367 | 2.2 x 2.3 | maker
5 | 1 | U4 nPM1300 PMIC: charger, fuel gauge, regulators | Nordic nPM1300 QFN32 | 5 x 5 | maker (height indicative)
6 | 1 | U5 64 Mbit low-power flash: the black box memory | Macronix MX25R6435F | 6 x 5 | indicative (WSON-8)
7 | 1 | U6 GNSS filter then LNA | to choose | 2 x 2 | indicative
8 | 1 | U7 Hold-up charger and ideal diode for C1 | to choose | 2.5 x 2 | indicative
9 | 1 | ANT1 Chip antenna 824-960 / 1710-2690 MHz | Ignion NN02-224 | 12 x 3 | distributor
10 | 1 | ANT2 GNSS patch antenna 18 mm | Taoglas CGGBP.18.4.A.02 | 18 x 18 | maker
11 | 1 | J1 USB-C receptacle (charge and black box readout) | to choose | 7.3 x 8.9 | indicative
12 | 1 | J2 eSIM, soldered MFF2 | to choose (IoT operator) | 5 x 6 | indicative
13 | 1 | J3 Battery connector JST-PH 2, SMD | to choose | 6 x 4.5 | indicative
14 | 1 | J4 SWD pads Tag-Connect TC2030 | footprint only | 8 x 4 | footprint
15 | 1 | SW1 Side button: arm, disarm, pair | to choose | 3.5 x 6 | indicative
16 | 1 | D1 Status LED 0603 | to choose | 1.6 x 0.8 | indicative
17 | 1 | LP1 Light pipe PMMA 3 mm | to choose | 3 x 3 | indicative
18 | 1 | C1 Hold-up supercapacitor | to size | 18 x 12 | indicative
19 | 1 | TS1 Tamper switch (mounting) | to choose | 6 x 6 | indicative
20 | 1 | PL1 Tamper plunger, 4 mm, spring loaded | to choose | 4 x 4 | indicative
21 | 1 | BT1 Li-Po 1S 2000 mAh, protected | Adafruit 2011 | 60 x 36 | distributor
22 | 1 | R1 CC1 pull-down 5.1 kOhm | 0402 | 1 x 0.5 | indicative
23 | 1 | R2 CC2 pull-down 5.1 kOhm | 0402 | 1 x 0.5 | indicative
24 | 1 | Base with strap ears | RL-HW-01 | 112 x 62 | CAD model
25 | 1 | Lid (non-metallic polymer) | RL-HW-02 | 92 x 62 | CAD model
26 | 4 | Plastic self-tapping screw | to choose | D2.7 | to define
27 | 1 | Adhesive foam under the battery | to choose | 60 x 36 x 0.5 | to define
28 | 1 | Strap or mounting plate | to choose | 25 wide | to define

Sources: hardware/netlist.json. 'indicative': size to be taken from the part chosen.

## - 92 x 62 x 22 mm (112 mm with the strap ears)

## - 23 electronic items, one cable inside

## - Cellular, satellite and DECT NR+ mesh from one SiP

## - Shock +-200 g, motion, tamper plunger, black box flash

## - Hold-up capacitor for the last message

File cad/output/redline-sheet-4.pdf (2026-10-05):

1

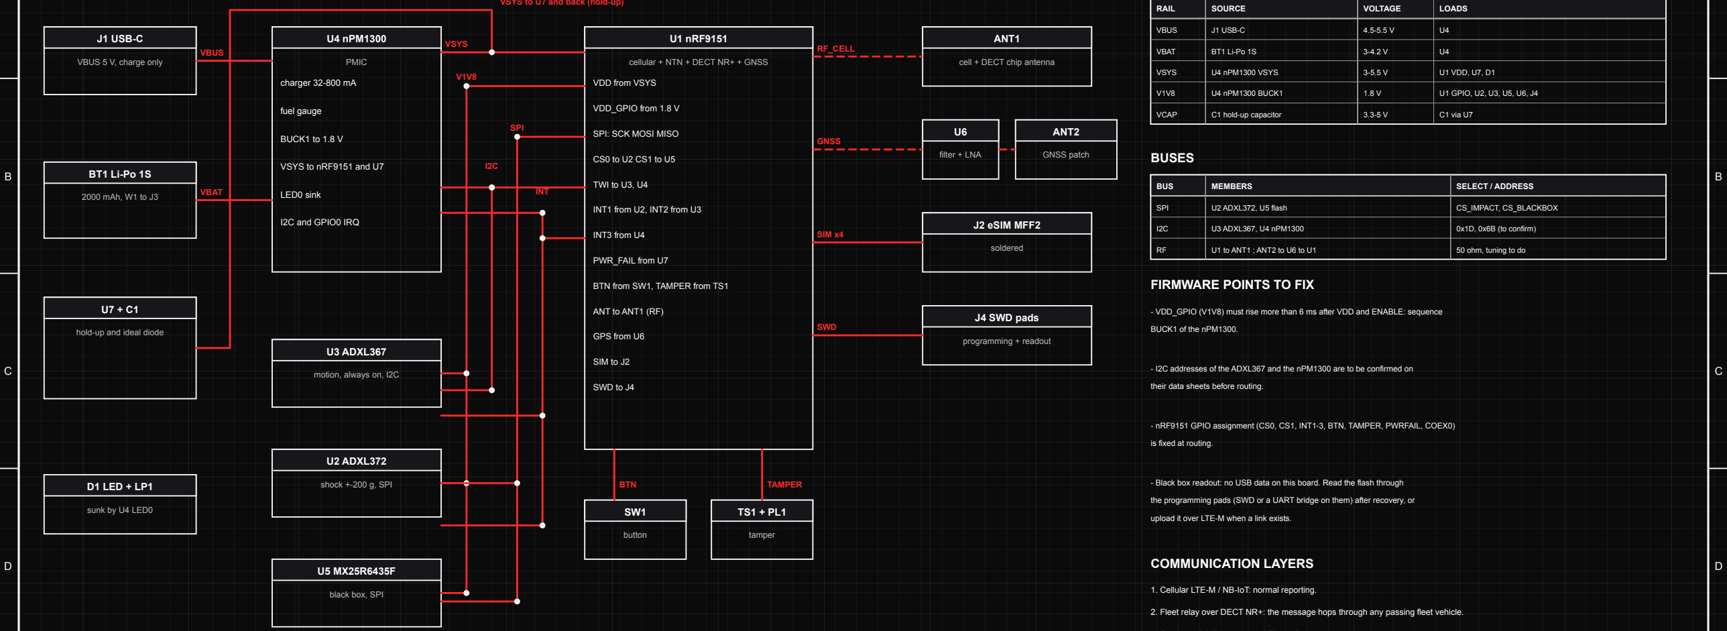
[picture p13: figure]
J1 USB-C; VBUS 5 V, charge only; 2000 mAh, W1 to J3; hold-up and ideal diode; U4 nPM1300; PMIC; charger 32-800 mA; fuel gauge; BUCK1 to 1.8 V; VSYS to nRF9151 and U7; LED0 sink; I2C and GPIO0 IRQ; U1 nRF9151; cellular + NTN + DECT NR+ + GNSS; VDD from VSYS; VDD_GPIO from 1.8 V; SPI: SCK MOSI MISO; TWI to U3, U4; INT1 from U2, INT2 from U3; INT3 from U4; PWR_FAIL from U7; BTN from SW1, TAMPER from TS1; ANT to ANT1 (RF); GPS from U6; SIM to J2; SWD to J4; ANT1; cell + DECT chip antenna; filter + LNA; ANT2; GNSS patch; J2 eSIM MFF2; soldered; J4 SWD pads; programming + readout; U3 ADXL367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
A | A
E | E
F | F
REDLINE / RL-MB-01 | CONCEPT STUDY - PROVISIONAL DIMENSIONS - DO NOT BUILD WITHOUT REVIEW
REV | DESCRIPTION | DATE
0 | Hardware concept RL-MB-01 | 2026-10-05

## GENERAL NOTES

1. Dimensions in mm. Third-angle projection. General tolerances to be defined (ISO 2768-m proposed).
2. Board outlines: maker or distributor data cited in hardware/netlist.json; others are indicative envelopes.
3. Heights, connectors and positions of openings are indicative and must be measured on the chosen parts.
4. Geometry and sheets generated by cad/generate.py (build123d 0.13.0); checks run with --check.

# ELECTRICAL ARCHITECTURE

Redline tracker and black box, board RL-MB-01 (nRF9151)

DRAWING NO.

## RL-EL-04

SCALE

## diagram, not to scale

REV
0

SHEET
4 / 5
DRAWN BY: M. ABAAQIL | DATE: 2026-10-05 | MATERIAL: to be defined

## BLOCK DIAGRAM FROM hardware/netlist.json

VSYS to U7 and back (hold-up)

Red solid: signals and supplies. Dashed: 50 ohm RF. One cable inside the device: W1 (BT1 to J3).

Hold-up: C1 0.5 F from 5 V to 3.3 V stores 3.53 J; the last-gasp budget needs 1.50 J (2.4x margin, assumptions in the netlist).

## RAILS (RANGES CHECKED)

V1V8 | U4 nPM1300 BUCK1 | 1.8 V | U1 GPIO, U2, U3, U5, U6, J4
RF | U1 to ANT1 ; ANT2 to U6 to U1 | 50 ohm, tuning to do
- VDD_GPIO (V1V8) must rise more than 6 ms after VDD and ENABLE: sequence
- I2C addresses of the ADXL367 and the nPM1300 are to be confirmed on
- nRF9151 GPIO assignment (CS0, CS1, INT1-3, BTN, TAMPER, PWRFAIL, COEX0)
- Black box readout: no USB data on this board. Read the flash through

the programming pads (SWD or a UART bridge on them) after recovery, or

upload it over LTE-M when a link exists.

1. Cellular LTE-M / NB-IoT: normal reporting.
2. Fleet relay over DECT NR+: the message hops through any passing fleet vehicle.
3. Satellite NB-NTN: optional, off by default. Needs its own L-band antenna.

Priority 3 (theft, tamper, power loss) leaves first on whichever layer is up.

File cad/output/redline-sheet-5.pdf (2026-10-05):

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
A | A
B | B
C | C
D | D
E | E
F | F
REDLINE / RL-MB-01 | CONCEPT STUDY - PROVISIONAL DIMENSIONS - DO NOT BUILD WITHOUT REVIEW
REV | DESCRIPTION | DATE
0 | Hardware concept RL-MB-01 | 2026-10-05

## GENERAL NOTES

1. Dimensions in mm. Third-angle projection. General tolerances to be defined (ISO 2768-m proposed).
2. Board outlines: maker or distributor data cited in hardware/netlist.json; others are indicative envelopes.
3. Heights, connectors and positions of openings are indicative and must be measured on the chosen parts.
4. Geometry and sheets generated by cad/generate.py (build123d 0.13.0); checks run with --check.

# WIRING AND NET LIST

## Redline tracker and black box, board RL-MB-01 (nRF9151)

DRAWING NO.

## RL-EL-05

### SCALE

## tables

### REV

0

### SHEET

5 / 5

DRAWN BY: M. ABAAQIL | DATE: 2026-10-05 | MATERIAL: to be defined

# NET LIST: 33 NETS, ALL TERMINALS UNIQUE (CHECKED)

NET | CLASS | TERMINALS
VBUS | power | J1.VBUS U4.VBUS
VBAT | power | BT1.+ J3.1 U4.VBAT
VSYS | power | U4.VSYS U1.VDD U7.VIN D1.A
VCAP | power | U7.CAP C1.+
V1V8 | power | U4.BUCK1 U1.VDD_GPIO U2.VDD U3.VDD U5.VCC U6.VCC J4.VREF
GND | ground | U4.GND U1.GND U2.GND U3.GND U5.GND U6.GND U7.GND C1.- +9
CC1 | signal | J1.CC1 R1.1
CC2 | signal | J1.CC2 R2.1
SPI_SCK | bus | U1.SPI_SCK U2.SCLK U5.SCLK
SPI_MOSI | bus | U1.SPI_MOSI U2.MOSI U5.SI
SPI_MISO | bus | U1.SPI_MISO U2.MISO U5.SO
CS_IMPACT | bus | U1.CS0 U2.CS
CS_BLACKBOX | bus | U1.CS1 U5.CS
I2C_SDA | bus | U1.TWI_SDA U3.SDA U4.SDA
I2C_SCL | bus | U1.TWI_SCL U3.SCL U4.SCL
INT_IMPACT | signal | U2.INT1 U1.GPIO_INT1
INT_MOTION | signal | U3.INT1 U1.GPIO_INT2
PMIC_INT | signal | U4.GPIO0 U1.GPIO_INT3
PWR_FAIL | signal | U7.PG U1.GPIO_PWRFAIL
RF_CELL | RF | U1.ANT ANT1.FEED
GNSS_ANT | RF | ANT2.FEED U6.IN
GNSS_RF | RF | U6.OUT U1.GPS
LNA_EN | signal | U1.COEX0 U6.EN
SIM_VCC | bus | U1.SIM_VCC J2.VCC
SIM_CLK | bus | U1.SIM_CLK J2.CLK
SIM_IO | bus | U1.SIM_IO J2.IO
SIM_RST | bus | U1.SIM_RST J2.RST
BUTTON | signal | SW1.1 U1.GPIO_BTN
TAMPER | signal | TS1.1 U1.GPIO_TAMPER
LED_SINK | signal | D1.K U4.LED0
SWDIO | bus | U1.SWDIO J4.SWDIO
SWDCLK | bus | U1.SWDCLK J4.SWDCLK
NRESET | signal | U1.RESET J4.RESET

# CONNECTOR PIN-OUTS

J1 USB-C | PIN | NET
| CC1 | CC1
| CC2 | CC2
| GND | GND
| VBUS | VBUS
J2 eSIM MFF2 | PIN | NET
| CLK | SIM_CLK
| GND | GND
| IO | SIM_IO
| RST | SIM_RST
| VCC | SIM_VCC
J3 Battery JST-PH 2 | PIN | NET
| 1 | VBAT
| 2 | GND
J4 SWD pads | PIN | NET
| GND | GND
| RESET | NRESET
| SWDCLK | SWDCLK
| SWDIO | SWDIO
| VREF | V1V8
SW1 Button | PIN | NET
| 1 | BUTTON
| 2 | GND
TS1 Tamper switch | PIN | NET
| 1 | TAMPER
| 2 | GND

# CABLE W1 (ONLY CABLE INSIDE)

## BT1 Li-Po

### 2000 mAh

J3

### red: VBAT

### black: GND

JST-PH 2 pins, 50 mm. Check polarity before plugging.

# POWER-UP SEQUENCE

1. VSYS from U4 (battery or USB-C).
2. VDD of U1 and ENABLE high.
3. BUCK1 starts 1.8 V more than 6 ms later.
4. VDD_GPIO then follows, sensors wake.
5. C1 charges through U7; PWR_FAIL goes high when full.
6. On a supply drop U7 keeps VSYS up and raises PWR_FAIL: last gasp.

# PASSIVE PARTS

### Decoupling, RF matching, pull-ups and level parts are

### added at routing; only R1 and R2 (USB-C CC pull-downs)

are modelled here because they define the connector.

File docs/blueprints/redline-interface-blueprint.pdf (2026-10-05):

1

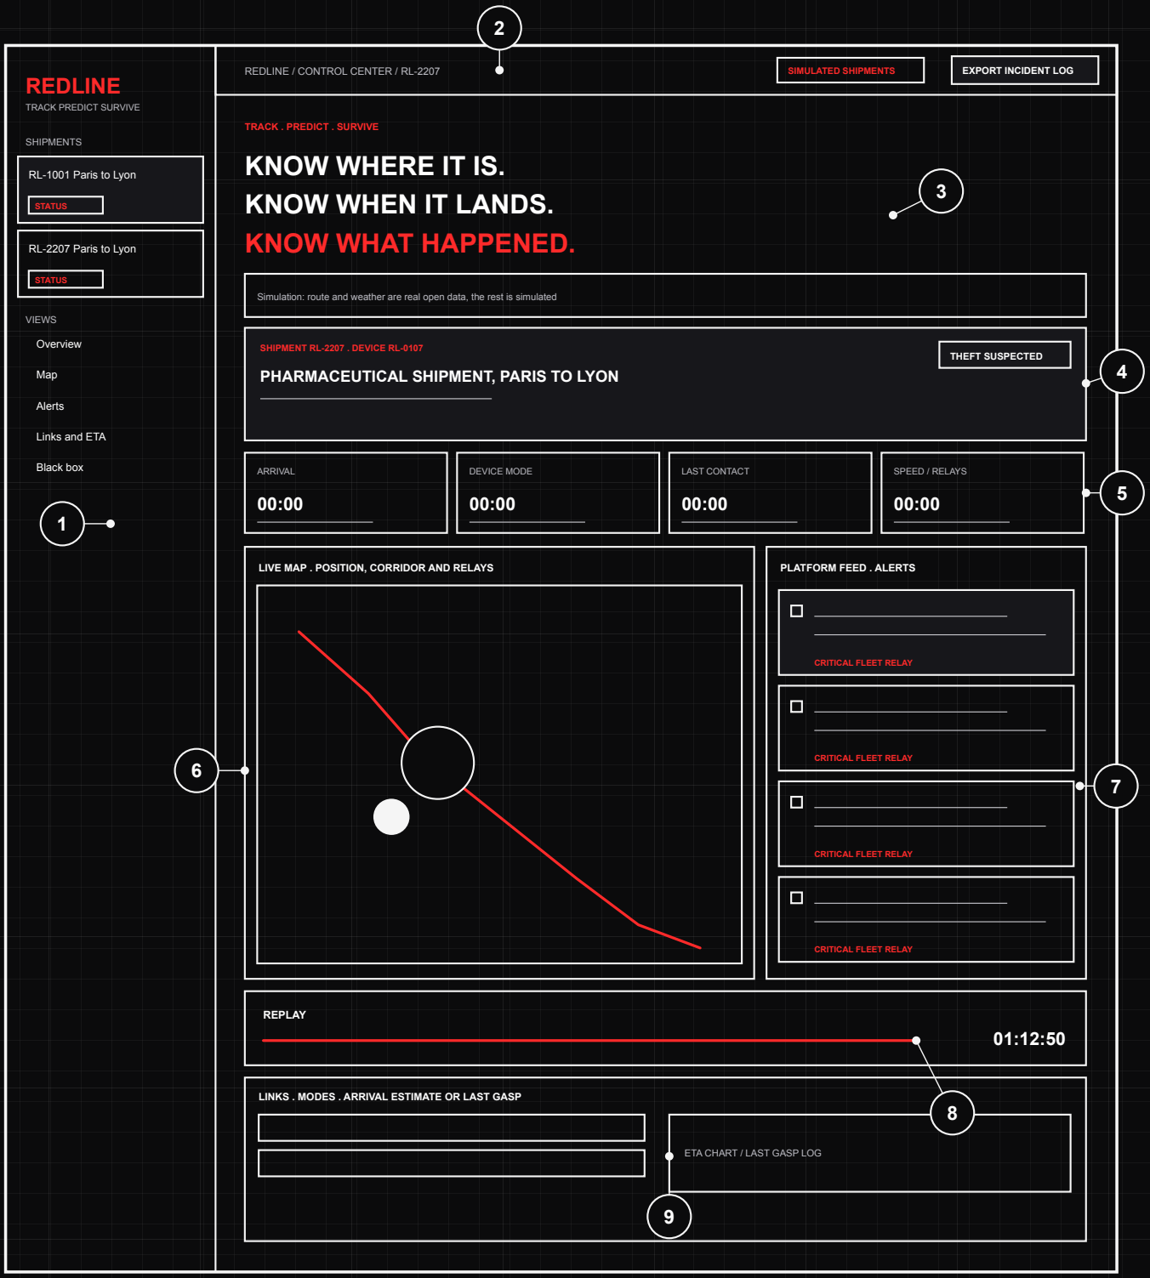
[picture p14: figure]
REDLINE; TRACK PREDICT SURVIVE; SHIPMENTS; RL-1001 Paris to Lyon; STATUS; RL-2207 Paris to Lyon; VIEWS; Overview; Map; Alerts; Links and ETA; Black box; TRACK . PREDICT . SURVIVE KNOW WHERE IT IS. KNOW WHEN IT LANDS. KNOW WHAT HAPPENED.; SHIPMENT RL-2207 . DEVICE RL-0107 PHARMACEUTICAL SHIPMENT, PARIS TO LYON; THEFT SUSPECTED; ARRIVAL 00:00; DEVICE MODE 00:00; LAST CONTACT 00:00; SPEED / RELAYS 00:00; CRITICAL FLEET RELAY; REPLAY; ETA CHART / LAST GASP LOG

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
A | A
B | B
C | C
D | D
E | E
F | F
REDLINE / RL-MB-01 | CONCEPT STUDY - PROVISIONAL DIMENSIONS - DO NOT BUILD WITHOUT REVIEW
REV | DESCRIPTION | DATE
0 | Dashboard interface plan | 2026-10-05

## GENERAL NOTES

1. Zones and labels taken from web/src/main.js; widths and grids from web/src/style.css.
2. CSS breakpoints: 1250 px, 930 px, 620 px (panels stack, sidebar hides on mobile).
3. Demo data in web/src/demo-trips.json: real route and weather, simulated vehicles and events.
4. Rule: the platform never shows an alert it has not received. Stored alerts are shown as stored.

# INTERFACE: CONTROL CENTER

## Redline control center (web/), desktop view at 1440 px

DRAWING NO.

## RL-UI-01

### SCALE

## about 0.14 mm / px

### REV

0

### SHEET

1 / 1

DRAWN BY: M. ABAAQIL | DATE: 2026-10-05 | MATERIAL: -
REDLINE / CONTROL CENTER / RL-2207 | SIMULATED SHIPMENTS | EXPORT INCIDENT LOG

Simulation: route and weather are real open data, the rest is simulated

LIVE MAP . POSITION, CORRIDOR AND RELAYS | PLATFORM FEED . ALERTS

LINKS . MODES . ARRIVAL ESTIMATE OR LAST GASP

# ZONE LIST

NO | ZONE | CONTENT | DATA / ACTION
1 | Sidebar | Logo, shipment cards with live status, view links | One card per shipment
2 | Top bar | Breadcrumb, simulation pill, export | CSV of the incident log
3 | Hero and notice | Promise, and what is real versus simulated | Always visible
4 | Shipment header | Title, cargo, vehicle, status chip | tripStatus()
5 | KPIs | Arrival, device mode, last contact, speed or relays | platformView()
6 | Live map | Corridor, plan, track, alerts, fleet relays | Leaflet + OpenStreetMap
7 | Alerts feed | What the platform received, and what is still stored on the device | Severity, channel, delay
8 | Replay | Scrub or play the whole trip | Filters what is known at time t
9 | Links, modes, ETA | Link and mode strips, plan versus live ETA, last gasp | eta.js, model.js

# DETAIL A: ALERT CARD (3:1)

Unauthorized stop | 00:28:00

### Stopped 10 min outside every authorized zone

HIGH | FLEET RELAY . RL-PEER-07 | DELIVERED 9 min LATER

### a severity dot

### b title and time of the event on the device

### c detail

### d severity, channel, delay before delivery

# USER FLOW

1. Pick a shipment (1), read its status chip and KPIs (4, 5).
2. Follow the alerts (7); each shows the channel it travelled and how late it arrived.
3. Click an alert to centre the map on it (6).
4. Replay (8) to see only what the platform knew at that moment.
5. Check the arrival estimate or the last gasp (9). Export the log (2).

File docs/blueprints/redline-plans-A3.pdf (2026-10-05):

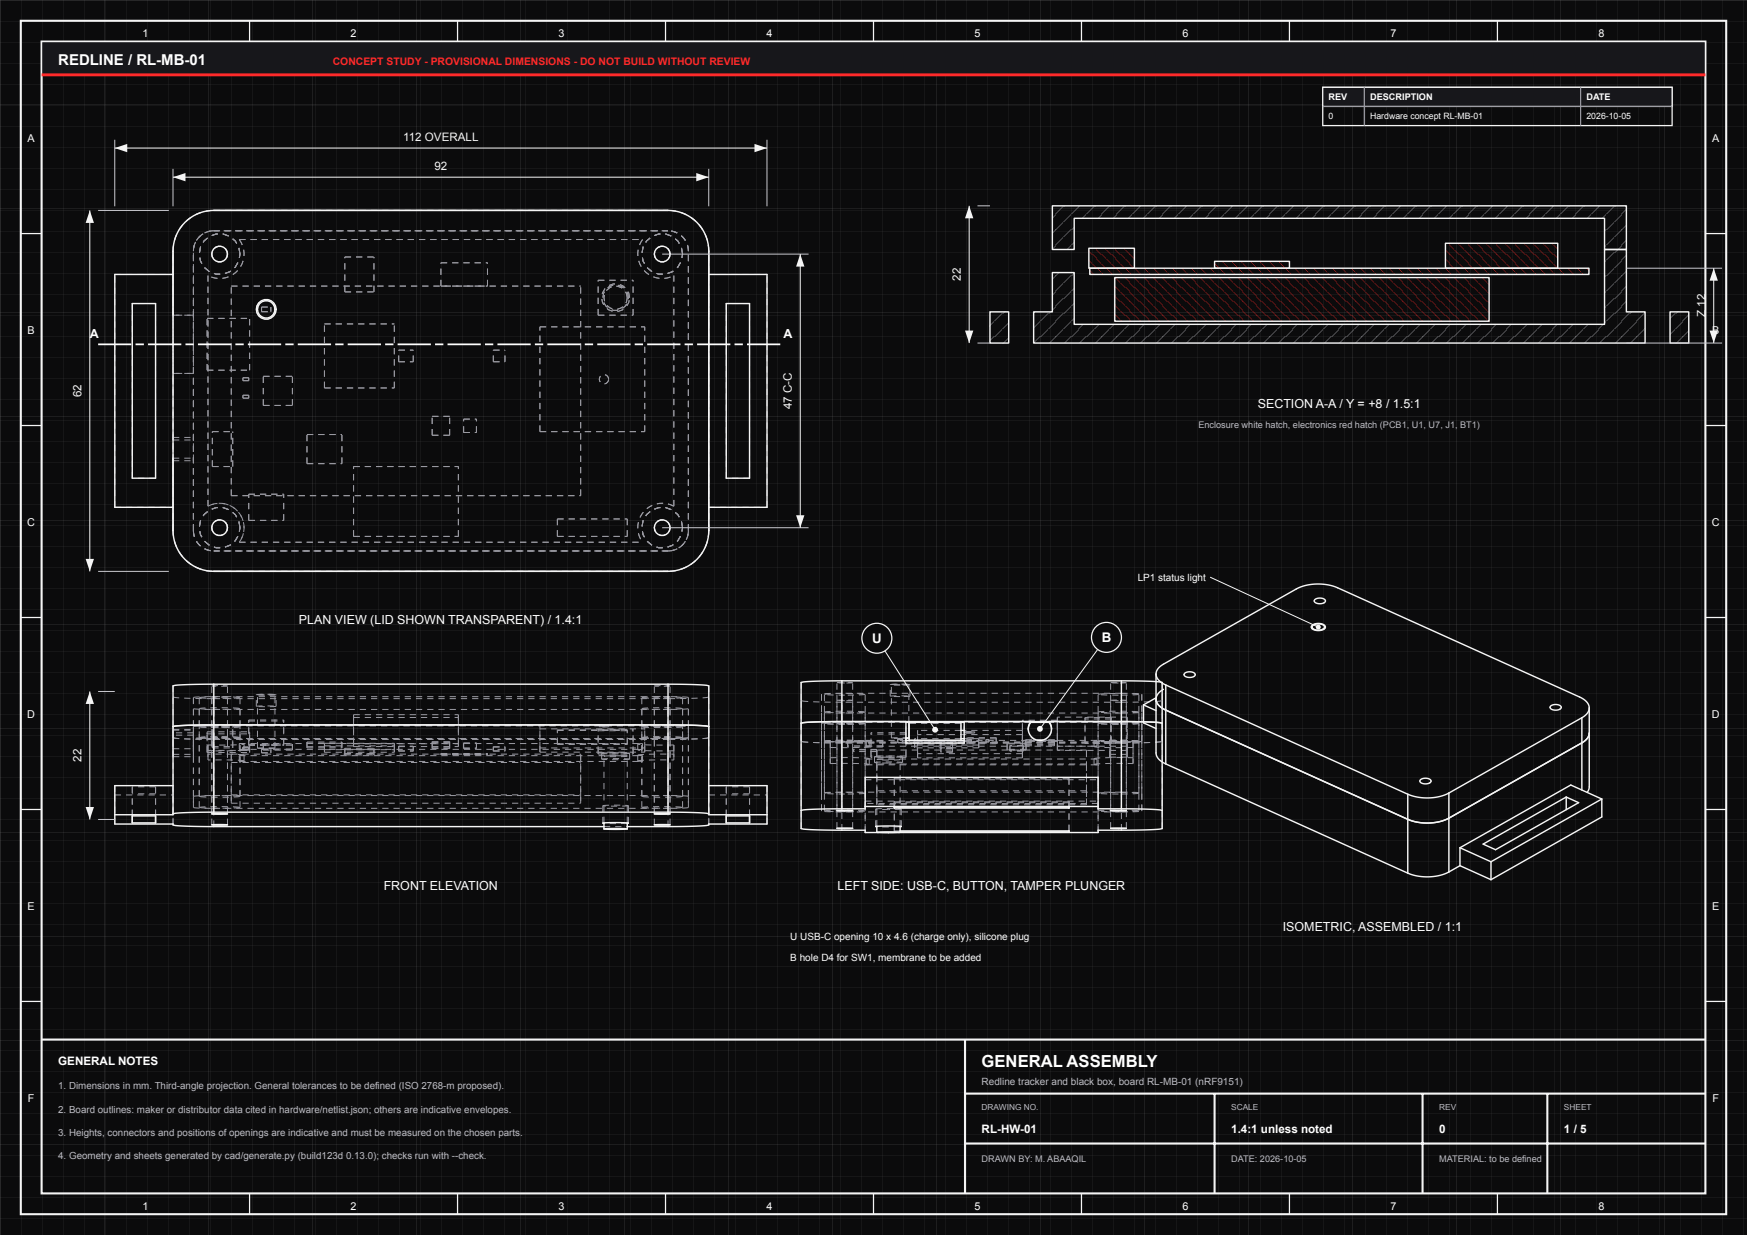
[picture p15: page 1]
REDLINE / RL-MB-01; CONCEPT STUDY - PROVISIONAL DIMENSIONS - DO NOT BUILD WITHOUT REVIEW; REV; DESCRIPTION; DATE; Hardware concept RL-MB-01; GENERAL NOTES; GENERAL ASSEMBLY; DRAWING NO. RL-HW-01; SCALE 1.4:1 unless noted; REV 0; SHEET 1 / 5; DRAWN BY: M. ABAAQIL; DATE: 2026-10-05; MATERIAL: to be defined; 112 OVERALL; FRONT ELEVATION; SECTION A-A / Y = +8 / 1.5:1; ISOMETRIC, ASSEMBLED / 1:1; LP1 status light

Enclosure white hatch, electronics red hatch (PCB1, U1, U7, J1, BT1)

PLAN VIEW (LID SHOWN TRANSPARENT) / 1.4:1

LEFT SIDE: USB-C, BUTTON, TAMPER PLUNGER

U USB-C opening 10 x 4.6 (charge only), silicone plug
B hole D4 for SW1, membrane to be added

1. Dimensions in mm. Third-angle projection. General tolerances to be defined (ISO 2768-m proposed).
2. Board outlines: maker or distributor data cited in hardware/netlist.json; others are indicative envelopes.

Redline tracker and black box, board RL-MB-01 (nRF9151)

3. Heights, connectors and positions of openings are indicative and must be measured on the chosen parts.

4. Geometry and sheets generated by cad/generate.py (build123d 0.13.0); checks run with --check.

A | A
B | B
C | C
D | D
E | E
0 | Hardware concept RL-MB-01 | 2026-10-05

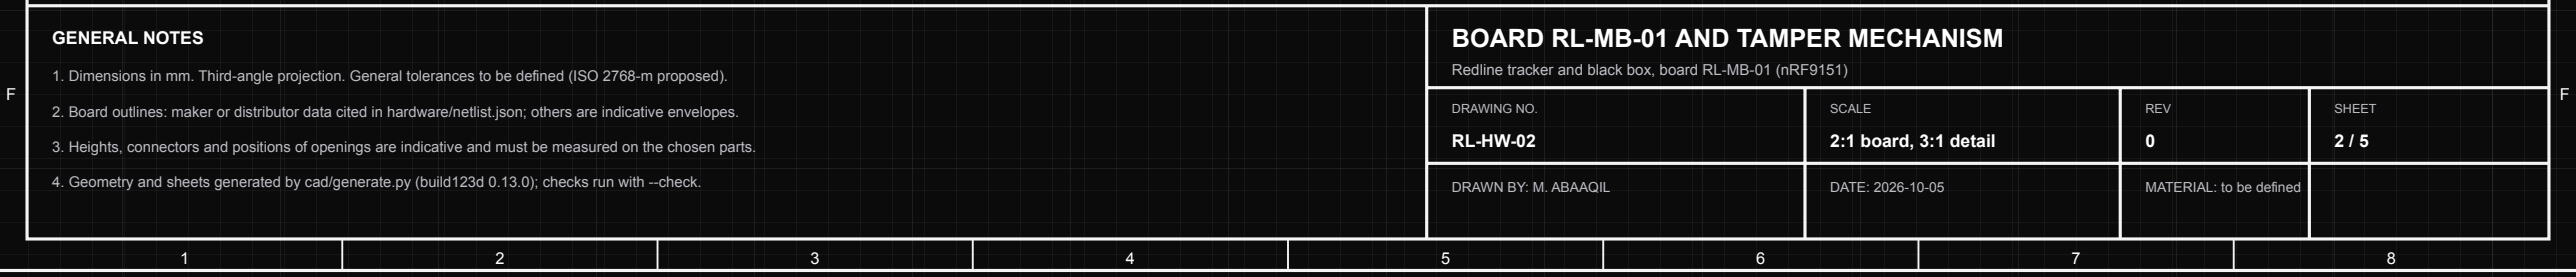
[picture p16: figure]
GENERAL NOTES; BOARD RL-MB-01 AND TAMPER MECHANISM; DRAWING NO. RL-HW-02; SCALE 2:1 board, 3:1 detail; REV 0; SHEET 2 / 5

1. Dimensions in mm. Third-angle projection. General tolerances to be defined (ISO 2768-m proposed).
2. Board outlines: maker or distributor data cited in hardware/netlist.json; others are indicative envelopes.

Redline tracker and black box, board RL-MB-01 (nRF9151)

ANTENNA KEEP-OUT (NO PARTS, NO COPPER)

U1 | 2
U4 | 5
U5 | 6 | 3 U2 | 4 U3

### 7 U6

U7 8

### 10 ANT2

### 9 ANT1

J1 | 11
SW1 | 15
D1 | 16 | J2 | 12
J3 | 13

## 14 J4

C1 18

### 19 TS1

R1 | 22
R2 | 23

52

### 01 BOARD RL-MB-01, COMPONENT SIDE / 2:1

Thickness 1 - notches R4.2 at the four screws - top face at Z = 12

### DETAIL B: TAMPER PLUNGER, SECTION Y = +16 / 3:1

Mounting surface pushes PL1 up: TS1 stays open. Remove the device: spring drops PL1, TS1 closes.

20

19

LID, INSIDE FACE / 0.75:1: D3.4 hole for the light pipe, no metal over ANT2

21 20

BASE WITH BT1 ON FOAM AND PL1 (BOARD REMOVED) / 0.75:1

LAYOUT RULES

- ANT1 at the board edge, keep-out clear of copper and parts (checked).
- ANT2 faces the polymer lid; nothing metallic above it.
- U2 near the centre of the board, held by four rigid points.
- BT1 under the board: check the antenna tuning with it in place.
- J1 and SW1 line up with the openings in the -X wall (checked).

A | A
0 | Hardware concept RL-MB-01 | 2026-10-05

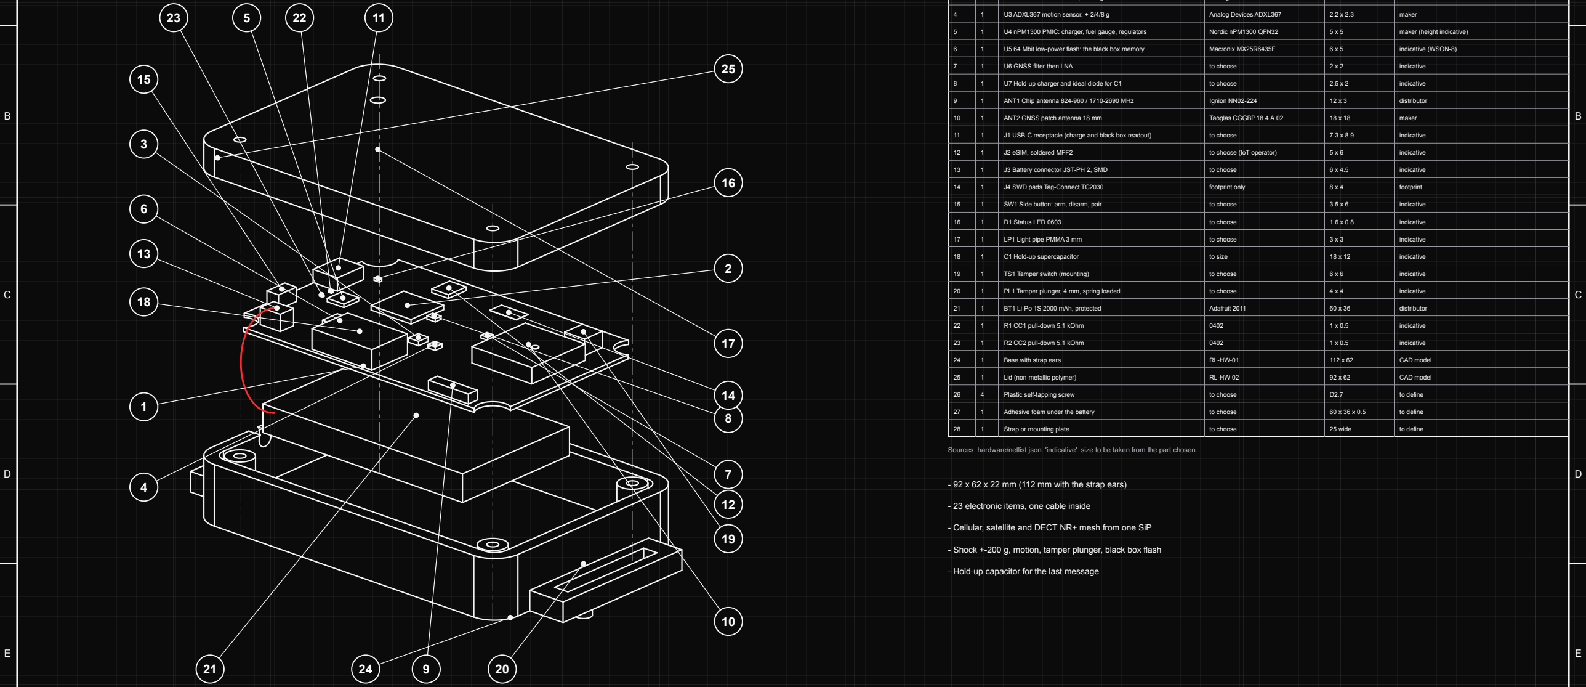
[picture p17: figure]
U6 GNSS filter then LNA; to choose; indicative; J2 eSIM, soldered MFF2; to choose (IoT operator); J4 SWD pads Tag-Connect TC2030; footprint only; footprint; D1 Status LED 0603; C1 Hold-up supercapacitor; to size; TS1 Tamper switch (mounting); R1 CC1 pull-down 5.1 kOhm; R2 CC2 pull-down 5.1 kOhm; Base with strap ears; CAD model; Lid (non-metallic polymer); Plastic self-tapping screw; to define; Adhesive foam under the battery; Strap or mounting plate; 25 wide; - 23 electronic items, one cable inside
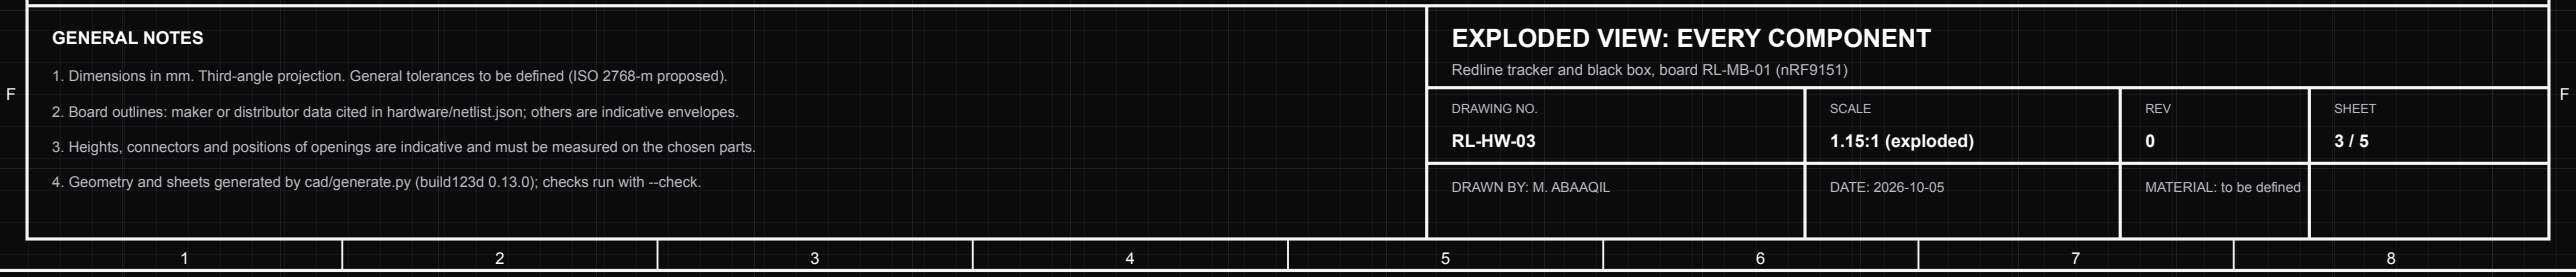
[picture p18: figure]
GENERAL NOTES; EXPLODED VIEW: EVERY COMPONENT; DRAWING NO. RL-HW-03; SCALE 1.15:1 (exploded); REV 0; SHEET 3 / 5

1. Dimensions in mm. Third-angle projection. General tolerances to be defined (ISO 2768-m proposed).
2. Board outlines: maker or distributor data cited in hardware/netlist.json; others are indicative envelopes.

Redline tracker and black box, board RL-MB-01 (nRF9151)

EXPLODED ISOMETRIC / 25 CALLOUTS / SCREW AXES IN CHAIN LINE / W1 BATTERY CABLE IN RED

## PARTS LIST

NO | QTY | DESIGNATION | PART | SIZE mm | DATA
1 | 1 | PCB1 Main board RL-MB-01 | Redline design | 80 x 52 | design choice
2 | 1 | U1 nRF9151 SiP: LTE-M, NB-IoT, NTN, DECT NR+, GNSS | Nordic nRF9151 | 12 x 11 | maker (height indicative)
3 | 1 | U2 ADXL372 shock sensor, +-200 g | Analog Devices ADXL372 | 3 x 3.25 | maker
4 | 1 | U3 ADXL367 motion sensor, +-2/4/8 g | Analog Devices ADXL367 | 2.2 x 2.3 | maker
5 | 1 | U4 nPM1300 PMIC: charger, fuel gauge, regulators | Nordic nPM1300 QFN32 | 5 x 5 | maker (height indicative)
6 | 1 | U5 64 Mbit low-power flash: the black box memory | Macronix MX25R6435F | 6 x 5 | indicative (WSON-8)
8 | 1 | U7 Hold-up charger and ideal diode for C1 | to choose | 2.5 x 2 | indicative
9 | 1 | ANT1 Chip antenna 824-960 / 1710-2690 MHz | Ignion NN02-224 | 12 x 3 | distributor
10 | 1 | ANT2 GNSS patch antenna 18 mm | Taoglas CGGBP.18.4.A.02 | 18 x 18 | maker
11 | 1 | J1 USB-C receptacle (charge and black box readout) | to choose | 7.3 x 8.9 | indicative
13 | 1 | J3 Battery connector JST-PH 2, SMD | to choose | 6 x 4.5 | indicative
15 | 1 | SW1 Side button: arm, disarm, pair | to choose | 3.5 x 6 | indicative
17 | 1 | LP1 Light pipe PMMA 3 mm | to choose | 3 x 3 | indicative
20 | 1 | PL1 Tamper plunger, 4 mm, spring loaded | to choose | 4 x 4 | indicative
21 | 1 | BT1 Li-Po 1S 2000 mAh, protected | Adafruit 2011 | 60 x 36 | distributor

Sources: hardware/netlist.json. 'indicative': size to be taken from the part chosen.

- 92 x 62 x 22 mm (112 mm with the strap ears)
- Cellular, satellite and DECT NR+ mesh from one SiP
- Shock +-200 g, motion, tamper plunger, black box flash
- Hold-up capacitor for the last message

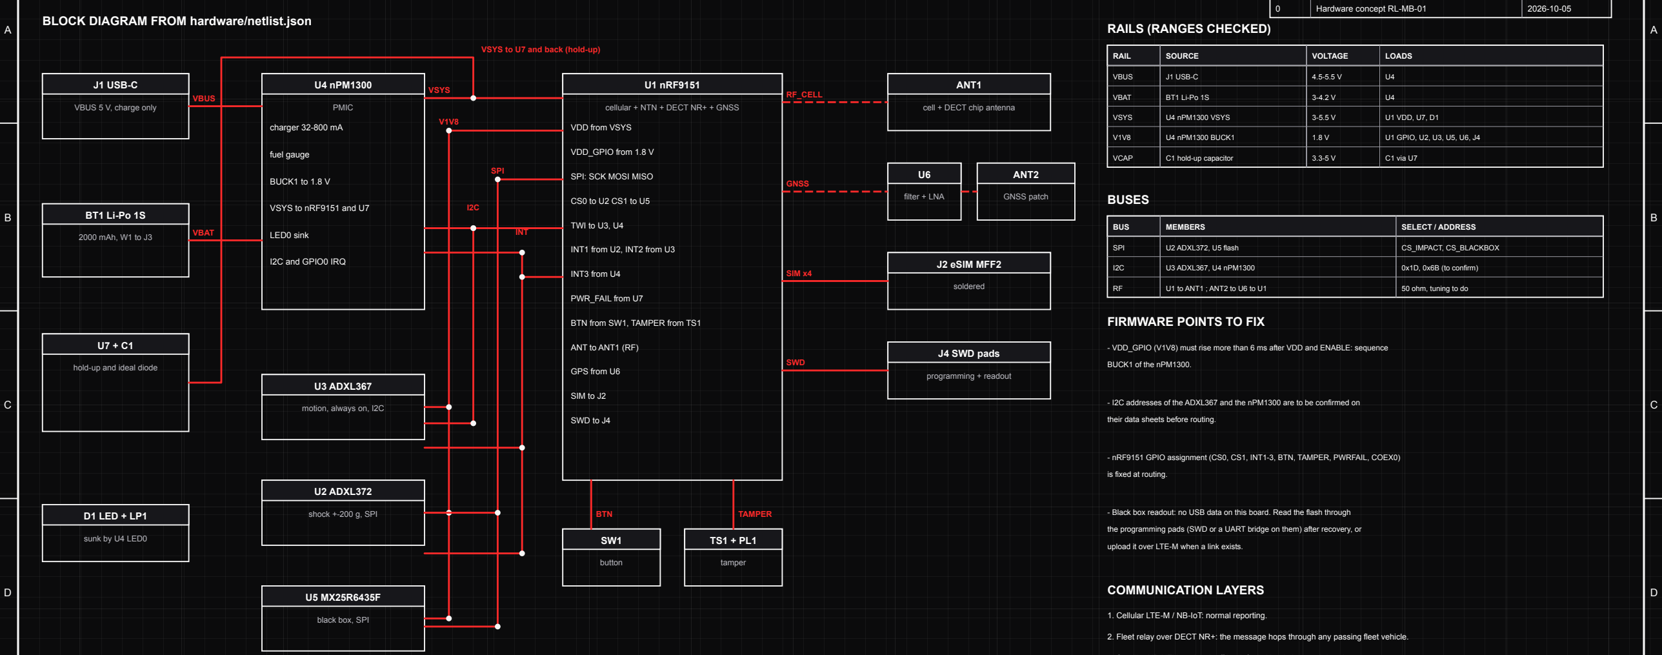
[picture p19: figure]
Hardware concept RL-MB-01; J1 USB-C; VBUS 5 V, charge only; 2000 mAh, W1 to J3; hold-up and ideal diode; U4 nPM1300; PMIC; charger 32-800 mA; fuel gauge; BUCK1 to 1.8 V; VSYS to nRF9151 and U7; LED0 sink; I2C and GPIO0 IRQ; U1 nRF9151; cellular + NTN + DECT NR+ + GNSS; VDD from VSYS; VDD_GPIO from 1.8 V; SPI: SCK MOSI MISO; TWI to U3, U4; INT1 from U2, INT2 from U3; INT3 from U4; PWR_FAIL from U7; BTN from SW1, TAMPER from TS1; ANT to ANT1 (RF); GPS from U6; SIM to J2; SWD to J4; ANT1; cell + DECT chip antenna; filter + LNA; ANT2; GNSS patch; J2 eSIM MFF2; soldered; J4 SWD pads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

E | E

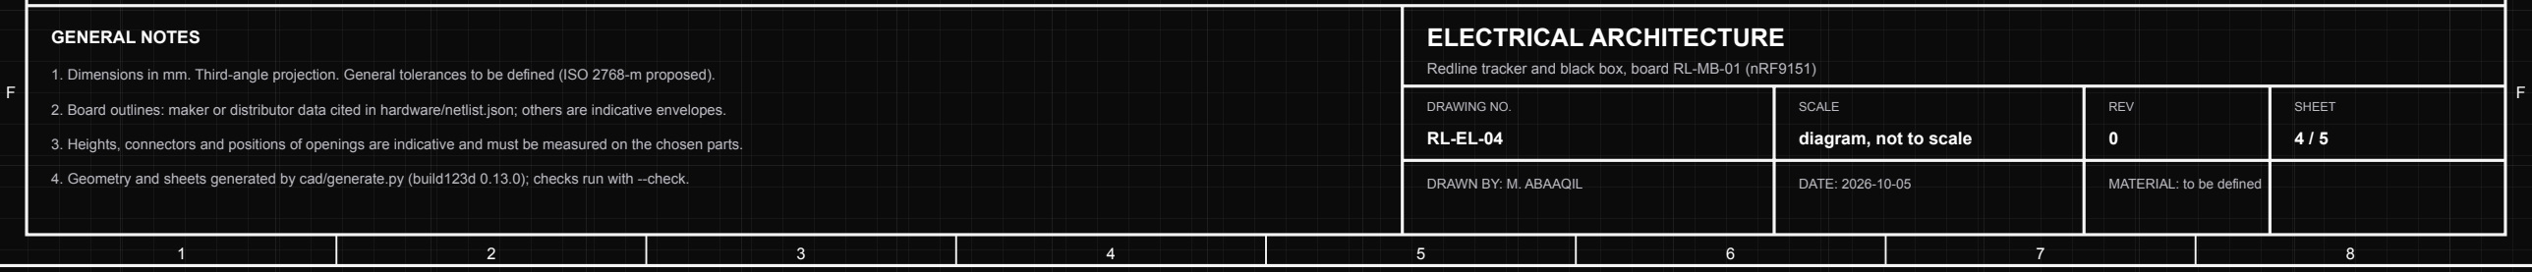
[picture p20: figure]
GENERAL NOTES; ELECTRICAL ARCHITECTURE; DRAWING NO. RL-EL-04; SCALE diagram, not to scale; REV 0; SHEET 4 / 5

1. Dimensions in mm. Third-angle projection. General tolerances to be defined (ISO 2768-m proposed).
2. Board outlines: maker or distributor data cited in hardware/netlist.json; others are indicative envelopes.

Redline tracker and black box, board RL-MB-01 (nRF9151)

### BLOCK DIAGRAM FROM hardware/netlist.json

Red solid: signals and supplies. Dashed: 50 ohm RF. One cable inside the device: W1 (BT1 to J3).

Hold-up: C1 0.5 F from 5 V to 3.3 V stores 3.53 J; the last-gasp budget needs 1.50 J (2.4x margin, assumptions in the netlist).

V1V8 | U4 nPM1300 BUCK1 | 1.8 V | U1 GPIO, U2, U3, U5, U6, J4
RF | U1 to ANT1 ; ANT2 to U6 to U1 | 50 ohm, tuning to do
- VDD_GPIO (V1V8) must rise more than 6 ms after VDD and ENABLE: sequence
- I2C addresses of the ADXL367 and the nPM1300 are to be confirmed on
- nRF9151 GPIO assignment (CS0, CS1, INT1-3, BTN, TAMPER, PWRFAIL, COEX0)
- Black box readout: no USB data on this board. Read the flash through

the programming pads (SWD or a UART bridge on them) after recovery, or

upload it over LTE-M when a link exists.

1. Cellular LTE-M / NB-IoT: normal reporting.
2. Fleet relay over DECT NR+: the message hops through any passing fleet vehicle.
3. Satellite NB-NTN: optional, off by default. Needs its own L-band antenna.

Priority 3 (theft, tamper, power loss) leaves first on whichever layer is up.

A | A
B | B
C | C
D | D
E | E
0 | Hardware concept RL-MB-01 | 2026-10-05

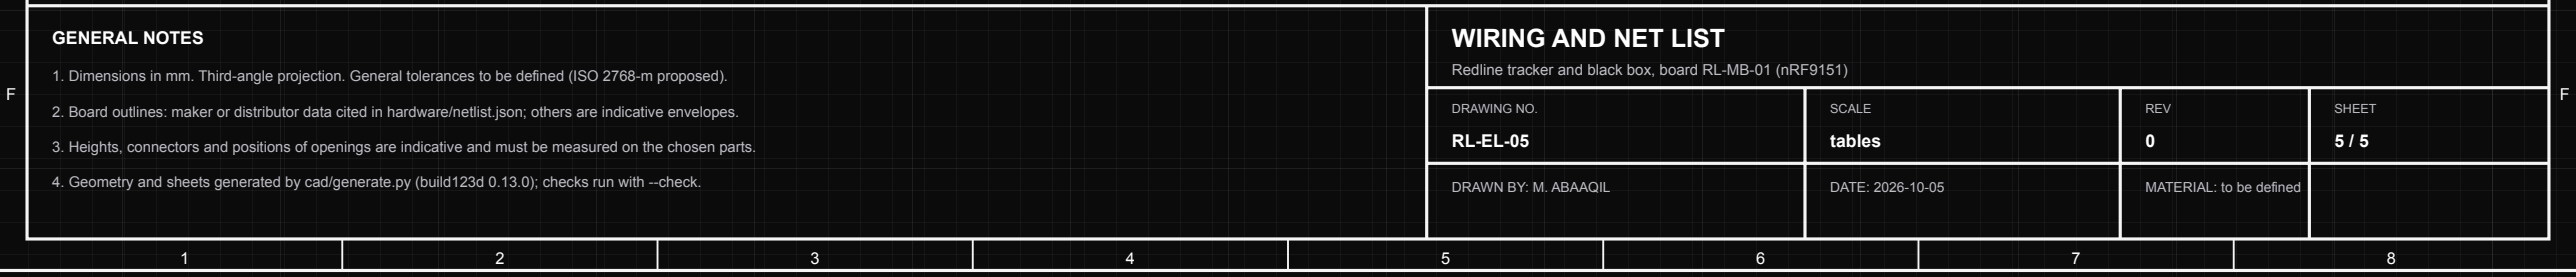
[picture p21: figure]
GENERAL NOTES; WIRING AND NET LIST; DRAWING NO. RL-EL-05; SCALE tables; REV 0; SHEET 5 / 5

1. Dimensions in mm. Third-angle projection. General tolerances to be defined (ISO 2768-m proposed).
2. Board outlines: maker or distributor data cited in hardware/netlist.json; others are indicative envelopes.

Redline tracker and black box, board RL-MB-01 (nRF9151)

### NET LIST: 33 NETS, ALL TERMINALS UNIQUE (CHECKED)

NET | CLASS | TERMINALS
VBUS | power | J1.VBUS U4.VBUS
VBAT | power | BT1.+ J3.1 U4.VBAT
VSYS | power | U4.VSYS U1.VDD U7.VIN D1.A
VCAP | power | U7.CAP C1.+
V1V8 | power | U4.BUCK1 U1.VDD_GPIO U2.VDD U3.VDD U5.VCC U6.VCC J4.VREF
GND | ground | U4.GND U1.GND U2.GND U3.GND U5.GND U6.GND U7.GND C1.- +9
CC1 | signal | J1.CC1 R1.1
CC2 | signal | J1.CC2 R2.1
SPI_SCK | bus | U1.SPI_SCK U2.SCLK U5.SCLK
SPI_MOSI | bus | U1.SPI_MOSI U2.MOSI U5.SI
SPI_MISO | bus | U1.SPI_MISO U2.MISO U5.SO
CS_IMPACT | bus | U1.CS0 U2.CS
CS_BLACKBOX | bus | U1.CS1 U5.CS
I2C_SDA | bus | U1.TWI_SDA U3.SDA U4.SDA
I2C_SCL | bus | U1.TWI_SCL U3.SCL U4.SCL
INT_IMPACT | signal | U2.INT1 U1.GPIO_INT1
INT_MOTION | signal | U3.INT1 U1.GPIO_INT2
PMIC_INT | signal | U4.GPIO0 U1.GPIO_INT3
PWR_FAIL | signal | U7.PG U1.GPIO_PWRFAIL
RF_CELL | RF | U1.ANT ANT1.FEED
GNSS_ANT | RF | ANT2.FEED U6.IN
GNSS_RF | RF | U6.OUT U1.GPS
LNA_EN | signal | U1.COEX0 U6.EN
SIM_VCC | bus | U1.SIM_VCC J2.VCC
SIM_CLK | bus | U1.SIM_CLK J2.CLK
SIM_IO | bus | U1.SIM_IO J2.IO
SIM_RST | bus | U1.SIM_RST J2.RST
BUTTON | signal | SW1.1 U1.GPIO_BTN
TAMPER | signal | TS1.1 U1.GPIO_TAMPER
LED_SINK | signal | D1.K U4.LED0
SWDIO | bus | U1.SWDIO J4.SWDIO
SWDCLK | bus | U1.SWDCLK J4.SWDCLK
NRESET | signal | U1.RESET J4.RESET

### CONNECTOR PIN-OUTS

J1 USB-C | PIN | NET
| CC1 | CC1
| CC2 | CC2
| GND | GND
| VBUS | VBUS
J2 eSIM MFF2 | PIN | NET
| CLK | SIM_CLK
| GND | GND
| IO | SIM_IO
| RST | SIM_RST
| VCC | SIM_VCC
J3 Battery JST-PH 2 | PIN | NET
| 1 | VBAT
| 2 | GND
J4 SWD pads | PIN | NET
| GND | GND
| RESET | NRESET
| SWDCLK | SWDCLK
| SWDIO | SWDIO
| VREF | V1V8
SW1 Button | PIN | NET
| 1 | BUTTON
| 2 | GND
TS1 Tamper switch | PIN | NET
| 1 | TAMPER
| 2 | GND

### CABLE W1 (ONLY CABLE INSIDE)

BT1 Li-Po

2000 mAh

J3

red: VBAT

black: GND

JST-PH 2 pins, 50 mm. Check polarity before plugging.

### POWER-UP SEQUENCE

1. VSYS from U4 (battery or USB-C).
2. VDD of U1 and ENABLE high.
3. BUCK1 starts 1.8 V more than 6 ms later.
4. VDD_GPIO then follows, sensors wake.
5. C1 charges through U7; PWR_FAIL goes high when full.
6. On a supply drop U7 keeps VSYS up and raises PWR_FAIL: last gasp.

### PASSIVE PARTS

Decoupling, RF matching, pull-ups and level parts are

added at routing; only R1 and R2 (USB-C CC pull-downs)

are modelled here because they define the connector.

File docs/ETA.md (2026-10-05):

# Arrival time

`web/src/eta.js`, tested by `web/src/eta.test.js` (8 tests). Pure functions: nothing calls the network, so every estimate can be replayed.

## Method

The remaining route is walked in 2 km chunks, advancing the clock. For each chunk the speed is

```
v = free-flow speed
    × rush-hour factor      (near the two ends of the trip, less on weekends)
    × weather factor        (rain, visibility, wind: from the Open-Meteo forecast)
    × fleet correction      (what the vehicle measured against the model, clamped 0.5 to 1.3, fading over 80 km)
  capped by any traffic situation published before "now"
```

Trucks are limited to 85 km/h. When 4.5 h of driving is reached, a 45-minute break is inserted once (a break already under way is respected). The engine returns the estimated arrival and the number of breaks.

## What is real and what is not

| Part | Status |
| --- | --- |
| Road geometry and free-flow speeds | Real: OpenStreetMap, routed by the public OSRM demo server, stored as a dated snapshot in `simulation/data/` |
| Weather | Real: Open-Meteo forecast for 6 points along the route, snapshot in `simulation/data/` |
| Rush-hour pattern | **Synthetic.** A smooth bump around 08:00 and 18:00 near the trip ends. It must be replaced by a measured weekly speed profile (168 values per road segment, as Valhalla supports) |
| Traffic accident | **Simulated**, injected as a DATEX II style record with a publication time |
| Vehicle speeds | **Simulated**, with noise, slow-downs, and extra slowing in real fog that the model only partly knows |

## Reading the result

In the delayed shipment the plan (made at departure, with the forecast) is 52 minutes off. The live estimate cannot see the accident before it is published, so for the first hours it is about as wrong as the plan: the 120-minute-before error is 44 min. After the publication and the observed slow-down it converges: 10 min at 60 minutes before arrival and 1 min at 15. This shows the mechanism; it is not a field accuracy figure.

## Using real traffic data

- **DATEX II.** European national access points publish situations (accidents, roadworks) in this format, for example [transport.data.gouv.fr](https://transport.data.gouv.fr/) in France. A situation maps to `{ fromM, toM, speedKmh, startMs, endMs, publishedMs }`: project its location onto the route with `nearestProgress` and keep its publication time.
- **Historical speeds.** [Valhalla](https://mapzen.com/blog/speed-tiles/) accepts 168 speeds per edge (one per hour of the week). Measured fleet speeds can build this profile over time, which would replace the synthetic pattern.
- **Licenses.** OpenStreetMap data is ODbL (attribution required). The public OSRM demo server is for light use: self-host it for anything real.

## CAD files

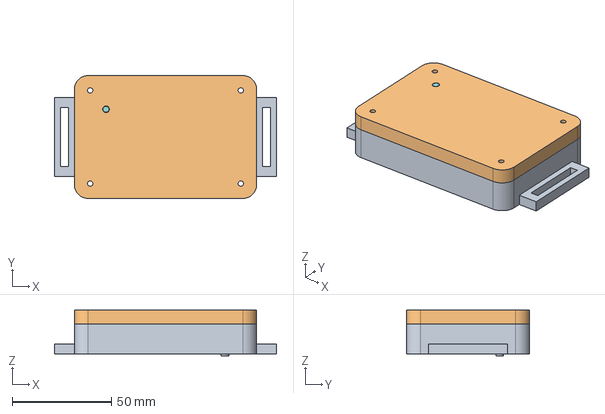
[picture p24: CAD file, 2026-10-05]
cad/output/redline-assembly.step
112.0 x 62.0 x 23.0 mm

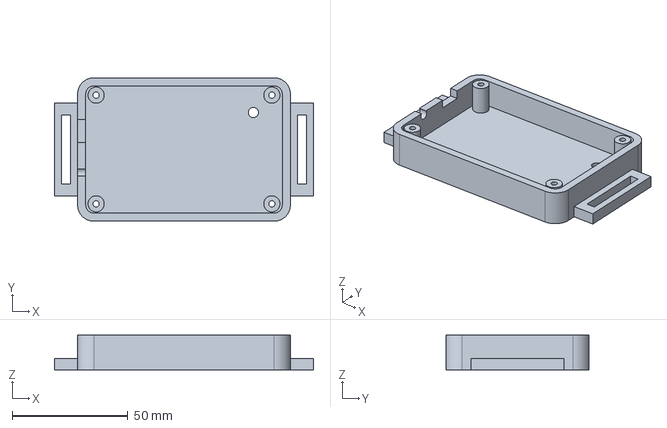
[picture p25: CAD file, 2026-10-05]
cad/output/redline-base.step
112.0 x 62.0 x 15.0 mm

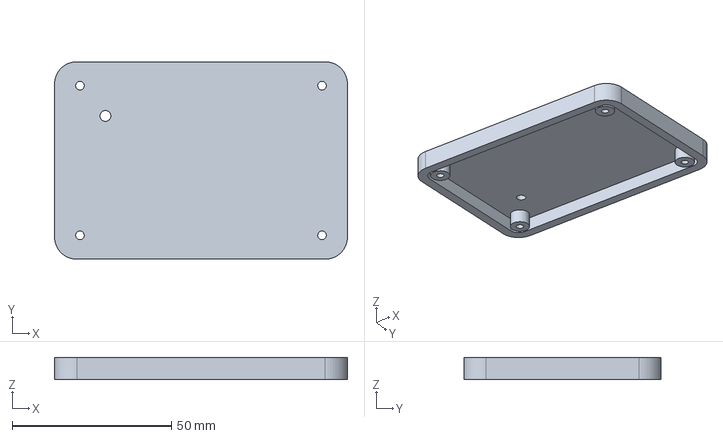
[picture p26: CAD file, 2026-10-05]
cad/output/redline-lid.step
92.0 x 62.0 x 7.00 mm

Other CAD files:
cad/output/redline-base.stl
cad/output/redline-lid.stl

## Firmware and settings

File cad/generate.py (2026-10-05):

#!/usr/bin/env python3
"""Parametric enclosure, board layout and A3 drawing set for Redline.

All dimensions are millimetres. Run with Python 3.12 and build123d 0.13.0.
The enclosure is a design study, not a measured or production-ready part.
Component outlines come from hardware/netlist.json; values marked "indicative"
there are envelopes used for clearance checks.
"""

from __future__ import annotations

import argparse
import math
import shutil
from dataclasses import dataclass
from pathlib import Path
import subprocess

from build123d import (
    Align, Box, Cylinder, Compound, Plane, Pos, Rot, Shape,
    export_step, export_stl, fillet, section,
)

from components import (
    ANT1_KEEPOUT, FLOORPLAN, PLUNGER_XY, build_parts, load_netlist, validate_netlist, wire_routes
)
from drafting import DATE, balloon, dim_h, dim_v, line, rect, sheet_start, table, txt

MIN = (Align.CENTER, Align.CENTER, Align.MIN)


@dataclass(frozen=True)
class Dimensions:
    length: float = 92
    width: float = 62
    height: float = 22
    base_height: float = 15
    wall: float = 3.5
    floor: float = 3
    roof: float = 2
    corner_radius: float = 7
    screw_x: float = 38
    screw_y: float = 23.5
    boss_radius: float = 3.5
    screw_diameter: float = 2.7
    # External strap ears at both ends, so the strap never crosses the cavity.
    ear_length: float = 10
    ear_thickness: float = 5
    strap_slot_width: float = 4
    strap_slot_length: float = 30
    # Main board RL-MB-01, held above the battery.
    pcb_length: float = 80
    pcb_width: float = 52
    pcb_thickness: float = 1.0
    pcb_z: float = 11.0
    pcb_notch_gap: float = 0.7
    foam: float = 0.5
    battery_x: float = -6
    # Openings: USB-C and side button in the -X wall, light pipe in the lid, tamper plunger in the floor.
    usb_y: float = 8
    usb_width: float = 10
    usb_height: float = 4.6
    button_y: float = -10
    button_d: float = 4
    light_pipe_d: float = 3
    light_hole_d: float = 3.4
    plunger_d: float = 4
    plunger_hole_d: float = 4.4
    min_clearance: float = 0.2


D = Dimensions()
ROOT = Path(__file__).resolve().parent
REPO = ROOT.parent
OUT = ROOT / "output"
SHEETS = 5


def rounded_box(length: float, width: float, height: float, z0: float, radius: float):
    solid = Pos(0, 0, z0) * Box(length, width, height, align=(Align.CENTER, Align.CENTER, Align.MIN))
    vertical = [e for e in solid.edges() if abs((e.end_point() - e.start_point()).Z) > height - 0.01]
    return fillet(vertical, radius)


def screw_centers(d: Dimensions):
    return [(x, y) for x in (-d.screw_x, d.screw_x) for y in (-d.screw_y, d.screw_y)]


def board_top(d: Dimensions):
    return d.pcb_z + d.pcb_thickness


def make_parts(d: Dimensions = D):
    # Open topped base. The cut extends through the top face.
    base = rounded_box(d.length, d.width, d.base_height, 0, d.corner_radius)
    cavity = rounded_box(d.length - 2*d.wall, d.width - 2*d.wall,
                         d.base_height - d.floor + 1, d.floor,
                         d.corner_radius - d.wall)
    base = base - cavity
    # Four coaxial pillars and through bores. The same centres drive the lid.
    for x, y in screw_centers(d):
        base += Pos(x, y, d.floor) * Cylinder(d.boss_radius, d.base_height-d.floor, align=MIN)
    for x, y in screw_centers(d):
        base -= Pos(x, y, -1) * Cylinder(d.screw_diameter/2, d.base_height+2, align=MIN)
    # Two end ears carry the strap outside the electronics volume.
    for sx in (-1, 1):
        ear_x = sx * (d.length/2 + d.ear_length/2 - 1)
        ear = Pos(ear_x, 0, 0) * Box(d.ear_length + 2, d.strap_slot_length + 10, d.ear_thickness, align=MIN)
        ear -= Pos(ear_x + sx, 0, -1) * Box(d.strap_slot_width, d.strap_slot_length, d.ear_thickness + 2, align=MIN)
        base += ear
    # USB-C and button openings, aligned with J1 and SW1 on the board.
    top = board_top(d)
    base -= Pos(-d.length/2, d.usb_y, top + 1.6 - d.usb_height/2) * Box(3*d.wall, d.usb_width, d.usb_height, align=MIN)
    base -= Pos(-d.length/2, d.button_y, top + 1.75) * Rot(0, 90, 0) * Cylinder(d.button_d/2, 3*d.wall)
    # Tamper plunger bore through the floor.
    base -= Pos(PLUNGER_XY[0], PLUNGER_XY[1], -1) * Cylinder(d.plunger_hole_d/2, d.floor + 2, align=MIN)

    # Cap is a separate hollow part. Its four sleeves meet the base pillars.
    lid_height = d.height - d.base_height
    lid = rounded_box(d.length, d.width, lid_height, d.base_height, d.corner_radius)
    lid -= rounded_box(d.length - 2*d.wall, d.width - 2*d.wall,
                       lid_height-d.roof+0.1, d.base_height-0.1,
                       d.corner_radius-d.wall)
    for x, y in screw_centers(d):
        lid += Pos(x, y, d.base_height) * Cylinder(d.boss_radius, lid_height-d.roof, align=MIN)
    for x, y in screw_centers(d):
        lid -= Pos(x, y, d.base_height-1) * Cylinder(d.screw_diameter/2, lid_height+2, align=MIN)
    lx, ly = FLOORPLAN["D1"]
    lid -= Pos(lx, ly, d.base_height) * Cylinder(d.light_hole_d/2, lid_height + 1, align=MIN)
    return base, lid, build_parts(d)


def check(parts, d: Dimensions = D):
    base, lid, electronics = parts
    validate_netlist(load_netlist())
    assert d.height > d.base_height
    assert d.screw_x + d.boss_radius < d.length/2-d.wall
    assert d.screw_y + d.boss_radius <= d.width/2-d.wall + 1e-6
    for part, z0, z1 in ((base, 0, d.base_height), (lid, d.base_height, d.height)):
        bb = part.bounding_box()
        assert abs(bb.size.Y-d.width) < 1e-5
        assert abs(bb.min.Z-z0) < 1e-5 and abs(bb.max.Z-z1) < 1e-5
        assert part.volume > 0
    assert abs(base.bounding_box().size.X - (d.length + 2*d.ear_length)) < 1e-5
    assert abs(lid.bounding_box().size.X - d.length) < 1e-5
    for x, y in screw_centers(d):
        probe = Pos(x, y, 0) * Cylinder(d.screw_diameter/2-0.1, d.height)
        assert base.intersect(probe) is None and lid.intersect(probe) is None
    # The USB-C and button openings really cross the wall in front of J1/SW1.
    top = board_top(d)
    for y, z in ((d.usb_y, top + 1.6), (d.button_y, top + 1.75)):
        probe = Pos(-d.length/2 - 1, y, z) * Box(2*d.wall + 2, 0.5, 0.5)
        assert base.intersect(probe) is None, f"Wall opening at y={y} is blocked"
    # Every part lies inside the cavity and keeps clear of walls, bosses and
    # every other part. Parts on PCB1 touch the board by design only.
    inner_x, inner_y = d.length/2 - d.wall, d.width/2 - d.wall
    board = next(p for p in electronics if p.ref == "PCB1")
    for p in electronics:
        bb = p.solid.bounding_box()
        assert bb.min.X >= -inner_x and bb.max.X <= inner_x, f"{p.ref} outside cavity in X"
        assert bb.min.Y >= -inner_y and bb.max.Y <= inner_y, f"{p.ref} outside cavity in Y"
        if p.in_cavity:
            assert bb.min.Z >= d.floor and bb.max.Z <= d.height - d.roof, f"{p.ref} outside cavity in Z"
        if p.on_board:
            assert abs(bb.min.Z - top) < 1e-6, f"{p.ref} not seated on PCB1"
            assert abs(bb.min.X) <= d.pcb_length/2 + 1 and abs(bb.max.X) <= d.pcb_length/2 + 1, f"{p.ref} off board"
            assert abs(bb.min.Y) <= d.pcb_width/2 and abs(bb.max.Y) <= d.pcb_width/2, f"{p.ref} off board"
            kx0, kx1, ky0, ky1 = ANT1_KEEPOUT
            if p.ref != "ANT1":
                assert bb.max.X <= kx0 or bb.min.X >= kx1 or bb.max.Y <= ky0 or bb.min.Y >= ky1, \
                    f"{p.ref} inside the LTE antenna keep-out"
        for shell, label in ((base, "base"), (lid, "lid")):
            gap = p.solid.distance_to(shell)
            assert gap >= d.min_clearance - 1e-6, f"{p.ref} touches {label} ({gap:.2f} mm)"
    for i, a in enumerate(electronics):
        for b in electronics[i+1:]:
            if {a.ref, b.ref} & {"PCB1"} and (a.on_board or b.on_board):
                continue
            gap = a.solid.distance_to(b.solid)
            assert gap >= d.min_clearance - 1e-6, f"{a.ref} touches {b.ref} ({gap:.2f} mm)"
    # No component hangs over a screw notch of the board.
    for p in electronics:
        if not p.on_board:
            continue
        bb = p.solid.bounding_box()
        for x, y in screw_centers(d):
            nx = min(max(x, bb.min.X), bb.max.X)
            ny = min(max(y, bb.min.Y), bb.max.Y)
            assert math.hypot(nx - x, ny - y) >= d.boss_radius + d.pcb_notch_gap, f"{p.ref} hangs over a board notch"
    refs = {c["ref"] for c in load_netlist()["components"]}
    assert refs == {p.ref for p in electronics}, "Netlist and CAD part list differ"
    assert board.solid.distance_to(base) >= d.min_clearance - 1e-6


# ---------------------------------------------------------------- projection

def polyline(edge, n=18):
    # Topological edges are projected by OpenCascade; sample curved edges for SVG.
    if edge.geom_type.name == "LINE":
        pts = [edge.start_point(), edge.end_point()]
    else:
        pts = [edge.position_at(i/n) for i in range(n+1)]
    return [(p.X, p.Y) for p in pts]


class View:
    """One orthographic projection; maps both edges and 3D points to the sheet."""

    def __init__(self, shape: Shape, camera, up, cx, cy, scale=1, look_at=(0, 0, 18)):
        self.camera, self.up, self.look_at = camera, up, look_at
        self.cx, self.cy, self.scale = cx, cy, scale
        self.vis, self.hid = shape.project_to_viewport(camera, up, look_at=look_at)
        pts = [p for e in self.vis for p in polyline(e)]
        self.midx = (min(p[0] for p in pts)+max(p[0] for p in pts))/2
        self.midy = (min(p[1] for p in pts)+max(p[1] for p in pts))/2

    def xy(self, x, y):
        return self.cx+(x-self.midx)*self.scale, self.cy-(y-self.midy)*self.scale

    def point(self, v):
        marker = Pos(v.X, v.Y, v.Z) * Box(.02, .02, .02)
        vis, hid = marker.project_to_viewport(self.camera, self.up, look_at=self.look_at)
        p = (vis + hid)[0].start_point()
        return self.xy(p.X, p.Y)

    def svg(self, hidden=True):
        def path_for(edges, cls):
            out = []
            for e in edges:
                coords = " ".join("%.3f,%.3f" % self.xy(x, y) for x, y in polyline(e))
                out.append(f'<polyline class="{cls}" points="{coords}"/>')
            return "".join(out)
        return (path_for(self.hid, "hidden") if hidden else "") + path_for(self.vis, "object")


def section_svg(sections, cx, cy, d: Dimensions, cls="hatch", scale=1.0):
    """Draw the real planar section faces with hatch fill and their boundary edges."""
    markup=[]
    def xy(point):
        return (cx + point.X*scale, cy + (d.height/2 - point.Z)*scale)
    def close(a,b):
        return abs(a.X-b.X)+abs(a.Z-b.Z)<1e-5
    for sk in sections:
        for face in sk.faces():
            edges=list(face.outer_wire().edges())
            if not edges:
                continue
            chain=[edges.pop(0)]
            while edges:
                tip=chain[-1].end_point()
                match=next(((i,e,False) for i,e in enumerate(edges) if close(e.start_point(),tip)),None)
                if match is None:
                    match=next(((i,e,True) for i,e in enumerate(edges) if close(e.end_point(),tip)),None)
                if match is None:
                    raise ValueError('Section perimeter not closed')
                i,e,reverse=match
                chain.append(e.reversed() if reverse else e)
                edges.pop(i)
            points=[]
            for edge in chain:
                samples=[edge.start_point(),edge.end_point()] if edge.geom_type.name=='LINE' else [edge.position_at(i/24) for i in range(25)]
                points.extend(samples[:-1])
            path=' '.join(f'{x:.3f},{y:.3f}' for x,y in map(xy,points))
            markup.append(f'<polygon points="{path}" style="fill:url(#{cls})" class="object"/>')
    return ''.join(markup)


def ring_positions(points, box, pad):
    """Spread balloons evenly around a rectangle, ordered by angle around its centre."""
    (x0, y0, x1, y1) = box
    cx, cy = (x0+x1)/2, (y0+y1)/2
    order = sorted(points, key=lambda kv: math.atan2(kv[1][1]-cy, kv[1][0]-cx))
    w, h = x1-x0+2*pad, y1-y0+2*pad
    perim = 2*(w+h)
    out = {}
    # Start the walk at the angle of the first item so leaders stay short.
    for i, (key, (px, py)) in enumerate(order):
        ang = math.atan2(py-cy, px-cx)
        t = (i + 0.5) / len(order)
        a = -math.pi + 2*math.pi*t
        a = (a + ang) / 2 if abs(a - ang) < math.pi/2 else a
        dx, dy = math.cos(a), math.sin(a)
        sx = (w/2) / abs(dx) if abs(dx) > 1e-9 else 1e9
        sy = (h/2) / abs(dy) if abs(dy) > 1e-9 else 1e9
        r = min(sx, sy)
        out[key] = (cx + dx*r, cy + dy*r)
    return out




# ------------------------------------------------------------------- sheets

def assembly(parts):
    base, lid, electronics = parts
    return Compound(children=[base, lid] + [p.solid for p in electronics])


def P(x, y, z):
    return Pos(x, y, z).position


def clipped(markup, x, y, w, h, name):
    return (f'<clipPath id="{name}"><rect x="{x}" y="{y}" width="{w}" height="{h}"/></clipPath>'
            f'<g clip-path="url(#{name})">{markup}</g>')


def sheet_one(parts, d: Dimensions):
    base, lid, electronics = parts
    full = assembly(parts)
    top_z = board_top(d)
    s = sheet_start(1, "GENERAL ASSEMBLY", "RL-HW-01", "1.4:1 unless noted", total=SHEETS)
    k = 1.4
    top = View(full, (0, 0, 200), (0, 1, 0), 106, 94, k)
    s.append(top.svg())
    s.append(txt(106, 150, "PLAN VIEW (LID SHOWN TRANSPARENT) / 1.4:1", 3, "label", "middle"))
    x0, x1 = top.point(P(-d.length/2, 0, d.height))[0], top.point(P(d.length/2, 0, d.height))[0]
    y0, y1 = top.point(P(0, d.width/2, d.height))[1], top.point(P(0, -d.width/2, d.height))[1]
    ex0, ex1 = top.point(P(-d.length/2-d.ear_length, 0, 0))[0], top.point(P(d.length/2+d.ear_length, 0, 0))[0]
    s.append(dim_h(x0, x1, y0-8, y0-1, f"{d.length:g}"))
    s.append(dim_h(ex0, ex1, y0-15, y0-1, f"{d.length+2*d.ear_length:g} OVERALL"))
    s.append(dim_v(y0, y1, ex0-6, x0-1, f"{d.width:g}"))
    sy0, sy1 = top.point(P(0, d.screw_y, d.height))[1], top.point(P(0, -d.screw_y, d.height))[1]
    sx1 = top.point(P(d.screw_x, 0, d.height))[0]
    s.append(dim_v(sy0, sy1, ex1+8, sx1, f"{2*d.screw_y:g} C-C"))
    cy = top.point(P(0, d.usb_y, 0))[1]
    s.append(line(ex0-4, cy, ex1+4, cy, "cut"))
    s.append(txt(ex0-6, cy-1.5, "A", 3, "label-bold")); s.append(txt(ex1+4, cy-1.5, "A", 3, "label-bold"))

    front = View(full, (0, -200, 10), (0, 0, 1), 106, 182, k)
    s.append(front.svg())
    s.append(txt(106, 214, "FRONT ELEVATION", 3, "label", "middle"))
    fy0, fy1 = front.point(P(0, 0, d.height))[1], front.point(P(0, 0, 0))[1]
    fx0 = front.point(P(-d.length/2-d.ear_length, 0, 0))[0]
    s.append(dim_v(fy0, fy1, fx0-6, fx0, f"{d.height:g}"))

    side = View(full, (-200, 0, 10), (0, 0, 1), 236, 182, k)
    s.append(side.svg())
    s.append(txt(236, 214, "LEFT SIDE: USB-C, BUTTON, TAMPER PLUNGER", 3, "label", "middle"))
    pu = side.point(P(-d.length/2, d.usb_y, top_z + 1.6))
    pb = side.point(P(-d.length/2, d.button_y, top_z + 1.75))
    s.append(balloon(pu[0], pu[1], pu[0]-14, pu[1]-22, "U"))
    s.append(balloon(pb[0], pb[1], pb[0]+16, pb[1]-22, "B"))
    s.append(txt(190, 226, f"U  USB-C opening {d.usb_width:g} x {d.usb_height:g} (charge only), silicone plug", 2.4, "label"))
    s.append(txt(190, 231, f"B  hole D{d.button_d:g} for SW1, membrane to be added", 2.4, "label"))

    # Exact section through J1 (Y = usb_y): board, connector, lid, base.
    cut = Plane(origin=(0, d.usb_y, 0), x_dir=(1, 0, 0), z_dir=(0, 1, 0))
    shells = [section(base, section_by=cut), section(lid, section_by=cut)]
    inner = [section(solid, section_by=cut) for p in electronics for solid in p.solid.solids()
             if solid.bounding_box().min.Y < d.usb_y < solid.bounding_box().max.Y]
    sc, scx, scy = 1.5, 322, 66
    s.append(section_svg(shells, scx, scy, d, scale=sc))
    s.append(section_svg(inner, scx, scy, d, "hatch2", scale=sc))
    s.append(txt(scx, 98, f"SECTION A-A / Y = +{d.usb_y:g} / 1.5:1", 3, "label", "middle"))
    s.append(txt(scx, 103, "Enclosure white hatch, electronics red hatch (PCB1, U1, U7, J1, BT1)", 2.2, "sub", "middle"))
    top_y, bot_y = scy - d.height/2*sc, scy + d.height/2*sc
    left = scx - (d.length/2 + d.ear_length)*sc
    s.append(dim_v(top_y, bot_y, left-5, left, f"{d.height:g}"))
    pcb_y = scy + (d.height/2 - top_z)*sc
    right = scx + (d.length/2 + d.ear_length)*sc
    s.append(dim_v(pcb_y, bot_y, right+6, scx + d.length/2*sc, f"Z {top_z:g}"))

    iso = View(full, (125, -140, 120), (0, 0, 1), 330, 176, 1.0, look_at=(0, 0, 10))
    s.append(iso.svg(hidden=False))
    s.append(txt(330, 224, "ISOMETRIC, ASSEMBLED / 1:1", 3, "label", "middle"))
    px, py = iso.point(P(*FLOORPLAN["D1"], d.height))
    s.append(line(px, py, px-26, py-12, "leader") + f'<circle cx="{px:.2f}" cy="{py:.2f}" r=".6" class="dot"/>')
    s.append(txt(px-27, py-11, "LP1 status light", 2.4, "label", "end"))
    s.append('</svg>')
    return ''.join(s)


def sheet_two(parts, d: Dimensions):
    base, lid, electronics = parts
    s = sheet_start(2, "BOARD RL-MB-01 AND TAMPER MECHANISM", "RL-HW-02", "2:1 board, 3:1 detail", total=SHEETS)
    top_z = board_top(d)
    on_board = [p for p in electronics if p.on_board]
    pcb = next(p for p in electronics if p.ref == "PCB1")
    k = 2.0
    v = View(Compound(children=[pcb.solid] + [p.solid for p in on_board]), (0, 0, 200), (0, 1, 0), 112, 104, k)
    kx0, kx1, ky0, ky1 = ANT1_KEEPOUT
    (ax, ay), (bx, by) = v.point(P(kx0, ky1, top_z)), v.point(P(kx1, ky0, top_z))
    s.append(f'<rect x="{ax:.2f}" y="{ay:.2f}" width="{bx-ax:.2f}" height="{by-ay:.2f}" style="fill:url(#hatch2)" class="frame"/>')
    s.append(v.svg(hidden=False))
    s.append(txt((ax+bx)/2, ay-1.5, "ANTENNA KEEP-OUT (NO PARTS, NO COPPER)", 2.1, "accent", "middle"))
    px0, py0 = v.point(P(-d.pcb_length/2, d.pcb_width/2, top_z))
    px1, py1 = v.point(P(d.pcb_length/2, -d.pcb_width/2, top_z))
    pts = {p.ref: v.point(P(p.ports["C"].X, p.ports["C"].Y, top_z)) for p in on_board}
    keys = [(p.find, pts[p.ref]) for p in on_board]
    spots = ring_positions(keys, (px0, py0, px1, py1), 13)
    for p in on_board:
        (x, y), (tx, ty) = pts[p.ref], spots[p.find]
        s.append(balloon(x, y, tx, ty, p.find))
        s.append(txt(tx + (5 if tx > (px0+px1)/2 else -5), ty + 1, p.ref, 2.0, "sub", "start" if tx > (px0+px1)/2 else "end"))
    s.append(dim_h(px0, px1, py0-27, py0-16, f"{d.pcb_length:g}"))
    s.append(dim_v(py0, py1, px1+30, px1+17, f"{d.pcb_width:g}"))
    s.append(txt(112, py1+32, "01 BOARD RL-MB-01, COMPONENT SIDE / 2:1", 3, "label", "middle"))
    s.append(txt(112, py1+37, f"Thickness {d.pcb_thickness:g} - notches R{d.boss_radius+d.pcb_notch_gap:g} at the four screws - top face at Z = {top_z:g}",
                 2.3, "sub", "middle"))

    # Tamper mechanism: exact section through the plunger (Y = plunger_y), clipped around it.
    pxm, pym = PLUNGER_XY
    cut = Plane(origin=(0, pym, 0), x_dir=(1, 0, 0), z_dir=(0, 1, 0))
    sc = 3.0
    ox, oy = 322, 68
    cx = ox - pxm * sc
    secs = [section(base, section_by=cut)]
    inner = []
    for p in electronics:
        if p.ref in ("PCB1", "TS1", "PL1", "ANT2", "BT1"):
            for solid in p.solid.solids():
                bb = solid.bounding_box()
                if bb.min.Y < pym < bb.max.Y:
                    inner.append(section(solid, section_by=cut))
    markup = section_svg(secs, cx, oy, d, scale=sc) + section_svg(inner, cx, oy, d, "hatch2", scale=sc)
    s.append(clipped(markup, ox - 42, oy - d.height/2*sc - 4, 84, d.height*sc + 8, "clipDetail"))
    s.append(rect(ox - 42, oy - d.height/2*sc - 4, 84, d.height*sc + 8, "frame"))
    s.append(txt(ox, oy + d.height/2*sc + 12, f"DETAIL B: TAMPER PLUNGER, SECTION Y = +{pym:g} / 3:1", 3, "label", "middle"))
    s.append(txt(ox, oy + d.height/2*sc + 17.5, "Mounting surface pushes PL1 up: TS1 stays open. Remove the device: spring drops PL1, TS1 closes.", 2.1, "sub", "middle"))
    pl = next(p for p in electronics if p.ref == "PL1")
    zc = (pl.solid.bounding_box().min.Z + pl.solid.bounding_box().max.Z) / 2
    qx, qy = ox, oy + (d.height/2 - zc) * sc
    s.append(balloon(qx, qy, ox + 30, qy + 6, pl.find))
    ts = next(p for p in electronics if p.ref == "TS1")
    s.append(balloon(ox, oy + (d.height/2 - (top_z + 2)) * sc, ox + 30, oy + (d.height/2 - (top_z + 2)) * sc - 10, ts.find))

    under = View(lid, (0, 0, -200), (0, 1, 0), 318, 148, 0.75)
    s.append(under.svg(hidden=False))
    s.append(txt(318, 178, f"LID, INSIDE FACE / 0.75:1: D{d.light_hole_d:g} hole for the light pipe, no metal over ANT2", 2.4, "label", "middle"))

    bt = next(p for p in electronics if p.ref == "BT1")
    lower = View(Compound(children=[base, bt.solid, pl.solid]), (0, 0, 200), (0, 1, 0), 318, 208, 0.75)
    s.append(lower.svg(hidden=False))
    c = lower.point(P(d.battery_x, 0, 10.5))
    s.append(balloon(c[0], c[1], c[0]+20, c[1]-22, bt.find))
    c2 = lower.point(P(PLUNGER_XY[0], PLUNGER_XY[1], 6))
    s.append(balloon(c2[0], c2[1], c2[0]+16, c2[1]-10, pl.find))
    s.append(txt(318, 242, "BASE WITH BT1 ON FOAM AND PL1 (BOARD REMOVED) / 0.75:1", 2.6, "label", "middle"))

    rules = ["LAYOUT RULES",
             "- ANT1 at the board edge, keep-out clear of copper and parts (checked).",
             "- ANT2 faces the polymer lid; nothing metallic above it.",
             "- U2 near the centre of the board, held by four rigid points.",
             "- BT1 under the board: check the antenna tuning with it in place.",
             "- J1 and SW1 line up with the openings in the -X wall (checked)."]
    for i, r in enumerate(rules):
        s.append(txt(14, 214 + i*5.4, r, 2.7 if i == 0 else 2.3, "label-bold" if i == 0 else "label"))
    s.append(line(222, 24, 222, 168, "thin"))
    s.append('</svg>')
    return ''.join(s)
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

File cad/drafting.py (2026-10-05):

"""Shared A3 sheet frame and drafting primitives for Redline drawings.

The look is a "blackprint": black paper, white lines, red for what matters.
Zone border A-F / 1-8, revision block and title block follow defence-style
drawing frames.
"""

from html import escape

DATE = "2026-10-05"
NOTES = [
    "1. Dimensions in mm. Third-angle projection. General tolerances to be defined (ISO 2768-m proposed).",
    "2. Board outlines: maker or distributor data cited in hardware/netlist.json; others are indicative envelopes.",
    "3. Heights, connectors and positions of openings are indicative and must be measured on the chosen parts.",
    "4. Geometry and sheets generated by cad/generate.py (build123d 0.13.0); checks run with --check.",
]


def txt(x, y, value, size=3, cls="label", anchor="start"):
    return f'<text x="{x:.2f}" y="{y:.2f}" class="{cls}" font-size="{size}" text-anchor="{anchor}">{escape(str(value))}</text>'


def line(x1, y1, x2, y2, cls="thin"):
    return f'<line x1="{x1:.2f}" y1="{y1:.2f}" x2="{x2:.2f}" y2="{y2:.2f}" class="{cls}"/>'


def rect(x, y, w, h, cls="frame"):
    return f'<rect x="{x:.2f}" y="{y:.2f}" width="{w:.2f}" height="{h:.2f}" class="{cls}"/>'


def dim_h(x1, x2, y, ey, label):
    return (line(x1, ey, x1, y - 2, "extension") + line(x2, ey, x2, y - 2, "extension") +
            line(x1, y, x2, y, "dimension") +
            f'<path class="arrow" d="M{x1:.2f},{y:.2f} l3,-1 l0,2 z M{x2:.2f},{y:.2f} l-3,-1 l0,2 z"/>' +
            txt((x1 + x2) / 2, y - 1.7, label, 2.8, "dimension-text", "middle"))


def dim_v(y1, y2, x, ex, label):
    mid = (y1 + y2) / 2
    return (line(ex, y1, x + 2, y1, "extension") + line(ex, y2, x + 2, y2, "extension") +
            line(x, y1, x, y2, "dimension") +
            f'<path class="arrow" d="M{x:.2f},{y1:.2f} l-1,3 l2,0 z M{x:.2f},{y2:.2f} l-1,-3 l2,0 z"/>' +
            f'<text x="{x - 2:.2f}" y="{mid:.2f}" transform="rotate(-90 {x - 2:.2f} {mid:.2f})" class="dimension-text" font-size="2.8" text-anchor="middle">{escape(str(label))}</text>')


def balloon(x, y, tx, ty, number):
    """Find-number balloon at (tx, ty) with a leader ending on a dot at (x, y)."""
    return (line(x, y, tx, ty, "leader") + f'<circle cx="{x:.2f}" cy="{y:.2f}" r=".7" class="dot"/>' +
            f'<circle cx="{tx:.2f}" cy="{ty:.2f}" r="3.6" class="balloon"/>' +
            txt(tx, ty + 1.15, number, 3.2, "label-bold", "middle"))


def table(x, y, widths, rows, row_h=5.2, header_size=2.3, size=2.15):
    out = [rect(x, y, sum(widths), row_h * len(rows), "frame")]
    for r, row in enumerate(rows):
        yy = y + r * row_h
        if r:
            out.append(line(x, yy, x + sum(widths), yy, "grid-line"))
        else:
            out.append(rect(x, yy, sum(widths), row_h, "head"))
        xx = x
        for c, (w, cell) in enumerate(zip(widths, row)):
            if c:
                out.append(line(xx, y, xx, y + row_h * len(rows), "grid-line"))
            out.append(txt(xx + 1.4, yy + row_h * 0.68, cell, header_size if r == 0 else size,
                           "label-bold" if r == 0 else "label"))
            xx += w
    return "".join(out)


STYLE = '''<style>
  .object{fill:none;stroke:#f5f5f5;stroke-width:.34;stroke-linecap:round;stroke-linejoin:round}
  .hidden{fill:none;stroke:#9a9aa2;stroke-width:.16;stroke-dasharray:1.5 1.2}
  .thin,.extension{fill:none;stroke:#c9c9cf;stroke-width:.16}
  .leader{stroke:#f5f5f5;stroke-width:.2}
  .dot{fill:#f5f5f5}
  .balloon{fill:#0b0b0c;stroke:#f5f5f5;stroke-width:.3}
  .dimension{stroke:#f5f5f5;stroke-width:.16} .dimension-text{font-family:Arial,sans-serif;fill:#f5f5f5}
  .arrow{fill:#f5f5f5} .label{font-family:Arial,sans-serif;fill:#fff}
  .label-bold{font-family:Arial,sans-serif;fill:#fff;font-weight:700}
  .sub{font-family:Arial,sans-serif;fill:#bdbdc4}
  .accent{font-family:Arial,sans-serif;fill:#ff2a2a;font-weight:700}
  .center{stroke:#9a9aa2;stroke-width:.15;stroke-dasharray:5 1 1 1}
  .cut{stroke:#fff;stroke-width:.42;stroke-dasharray:8 1 2 1}
  .frame{fill:none;stroke:#f5f5f5;stroke-width:.3}
  .border{fill:none;stroke:#f5f5f5;stroke-width:.5}
  .grid-line{stroke:#9a9aa2;stroke-width:.15}
  .head{fill:#17171b;stroke:#f5f5f5;stroke-width:.3}
  .wire{fill:none;stroke:#ff2a2a;stroke-width:.45;stroke-linecap:round;stroke-linejoin:round}
  .wire-rf{fill:none;stroke:#ff2a2a;stroke-width:.45;stroke-dasharray:2 .8}
  .pin{fill:#f5f5f5}
</style>'''

DEFS = '''<defs>
  <pattern id="grid-small" width="5" height="5" patternUnits="userSpaceOnUse"><path d="M5 0H0V5" fill="none" stroke="#ffffff" stroke-width=".08" opacity=".10"/></pattern>
  <pattern id="grid-large" width="25" height="25" patternUnits="userSpaceOnUse"><path d="M25 0H0V25" fill="none" stroke="#ffffff" stroke-width=".14" opacity=".16"/></pattern>
  <pattern id="hatch" width="2.6" height="2.6" patternUnits="userSpaceOnUse" patternTransform="rotate(45)"><path d="M0 0 V2.6" stroke="#d6d6dc" stroke-width=".18"/></pattern>
  <pattern id="hatch2" width="1.6" height="1.6" patternUnits="userSpaceOnUse" patternTransform="rotate(-45)"><path d="M0 0 V1.6" stroke="#ff2a2a" stroke-width=".18"/></pattern>
</defs>
<rect width="420" height="297" fill="#0b0b0c"/>
<rect width="420" height="297" fill="url(#grid-small)"/>
<rect width="420" height="297" fill="url(#grid-large)"/>'''
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

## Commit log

2026-10-05 Core: tested firmware logic for route, stops, theft score, black box, last gasp and relay queue
    RedlineCore.h is plain C++11 without heap or dependencies, so the same code runs in
    the tests, in the trip simulation and on the device. 9 test groups.
2026-10-05 Hardware: nRF9151 board RL-MB-01 with checks, enclosure model and five A3 sheets
    - netlist with sourced parts, rails, buses, hold-up budget and the single cable
    - parametric enclosure with tamper plunger, USB-C and button openings
    - checks: fit and clearances, antenna keep-out, rail ranges, bus addresses, hold-up energy
    - sheets: assembly, board and tamper detail, exploded view, architecture, wiring
    [redline-assembly.step, redline-base.step, redline-base.stl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]
2026-10-05 Control center, ETA engine, branding and interface blueprint
    - dashboard: map, alerts with channel and delay, replay, ETA chart, last gasp, black box
    - eta.js: breaks, rush hour, weather, published incidents, fleet correction (8 tests)
    - red and black brand with the slanted I of TiltAlert
    - interface blueprint and architecture, ETA, mesh and privacy docs
    [generate.py]
2026-10-05 README: pitch with problem, solution, simulated demos, blueprints and honest status
